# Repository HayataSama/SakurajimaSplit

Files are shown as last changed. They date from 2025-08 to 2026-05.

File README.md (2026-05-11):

# SakurajimaSplit

SakurajimaSplit is a 6x3 column stagger split mechanical keyboard. It's inspired by [Corne](https://github.com/foostan/crkbd), [Kyria](https://github.com/splitkb/kyria) and [Elephant42](https://github.com/illness072/elephant42).

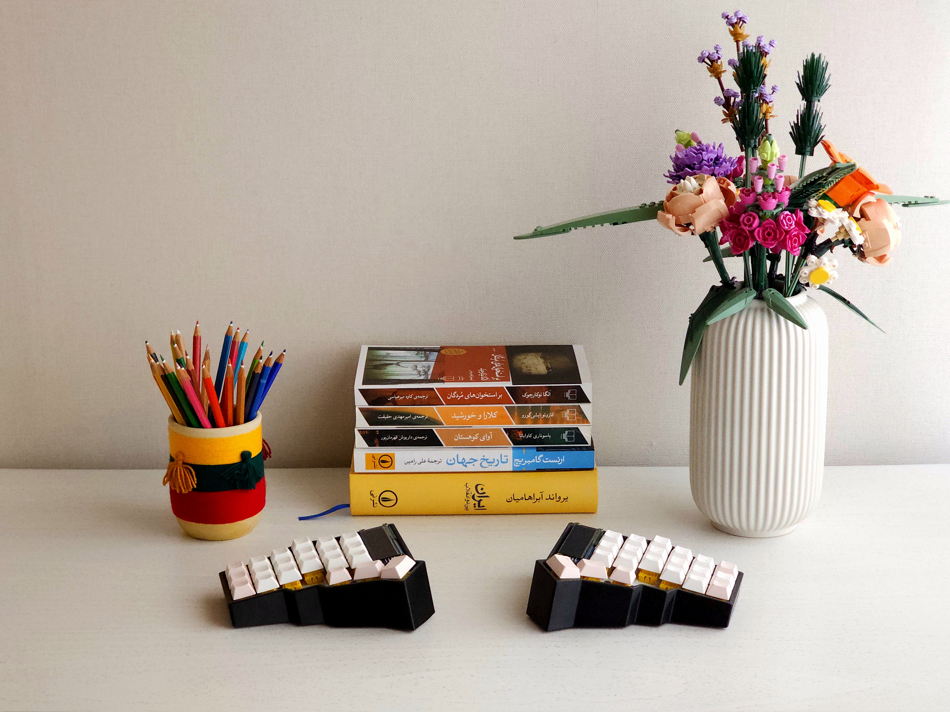
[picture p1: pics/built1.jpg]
SakurajimaSplit Fully Built


> [!NOTE]
> The master branch contains the most recent commits and is not meant for production. Gerbers and production files are available as a github release.
>
> This project was was made in KiCad 9.0 and FreeCAD 1.0. In addition to KiCad's default libraries, I used the [ebastler's marbastlib](https://github.com/ebastler/marbastlib) footprint and symbol library and [zykrah's kicad-kle-placer](https://github.com/zykrah/kicad-kle-placer) plugin. Using other versions may introduce bugs and/or inconsistencies therefore is discouraged.

## Features

- QMK compatible
- Cherry MX switch profile
- 3-Key thumb cluster
- 10-Degree sideways tilt
- SSD1305 OLED display
- W25Q Flash Storage for storing animations
- USB-C connector

## Motivation

I've been interested in mechanical keyboard for a few years now. I got my endgame keyboard (Mode Envoy) a while back and it's been my daily driver since. A while ago I suddenly became interested in split mechanical keyboards. Something about them being tiny and portable, also having this cyberpunky feeling made them appealing to me.

Apparently ortholinear keyboards are also more comfortable to type on. (Not sure how true this is but now that I've built this keyboard and am using it on daily basis, I should say it feels so damn nice to type with!)

I'm also an electrical engineering student and I have some experience designing PCBs. With all these in mind I thought, why not? Why not build a fully custom keyboard, tailored exactly to my needs? A few months later and here we are!

## Why Sakurajima?

Because Mai Sakurajima is the best girl.

## The Journey and Some Notes

This was my first experience designing a keyboard (and a handheld device in general). My approach for designing the layout was to put my fingers on a piece of paper (in the supposedly most comfortable position) and mark under each of my fingertips to find the best position for the home row. Then I measured the distance between keys and rounded them up to the closest standard value. (keyboard "u" units).

For the thumb cluster in addition to the fingertip, I also marked my thumb's joint (MCP joint?) on the paper to find the center of the circle where the thumb keys would be placed. Then I did some basic geometry to find the angle and distance of each key with respect to the center.

I don't know if this is the best approach or even a good approach, but it was fairly easy to do and the end result is great.

Let's talk about electronics. I know I've used a lot a questionable components in this keyboard, one's that are not generally common in keyboards or are not easily found. Believe me, I asked myself this question so many times too! Jokes aside, there were 3 main factors contributing to the component selection. First, this was a one off keyboard that I wanted to make for myself, so price didn't matter. Second, I wanted to try using different parts in my board from what I usually use, to gain more experience about electronics and get a feel for different components. And third (and probably the most important), I live in a heavily sanctioned country, so I don't have easy access to many electronic components because distributors like DigiKey or Mouser don't operate here. I had to work with what was available on the market.

This lead to some weird and frustrating design decisions that I regret.

The first mistake was choosing an SSD1305-based OLED display. I chose this specific display because it's panel was much larger than most common OLED displays on the market and I thought it would look good on the keyboard. The OLED driver is very similar to SSD1306 but is not officially supported by QMK. This is not a big problem by itself as QMK is an open-source firmware and you're free to modify the source code to add support for your display. The main problem is that this OLED module is 128x33 pixels and not 128x32 pixels like most OLED modules are! This creates many memory related issues and incompatibility with QMK which I have yet to solve!

The next not so great decision was choosing a WSON package for hand soldering! The voltage regulator IC is very very tiny and without proper tools like a microscope and a hotplate (which I don't have) is very difficult to hand solder. I don't know what I was thinking when picking parts, but now I've learned (the hard way!) to pay more attention to package sizes.

A big missed opportunity was not making this keyboard wireless. I could probably use an STM32 W-series MCU to make this keyboard Bluetooth-enabled. At the time, I chose to not go this route mainly because I wanted to keep things simple and build something that actually just works. I might create a new revision of this keyboard, fix the stated issues (and some others) and add new features like wireless connectivity in the future.

## Limitations

QMK doesn't currently support W25Q flash storages. I plan on writing a driver for these ICs and add it to QMK in the future, but for now this chip is basically useless.

## Gallery

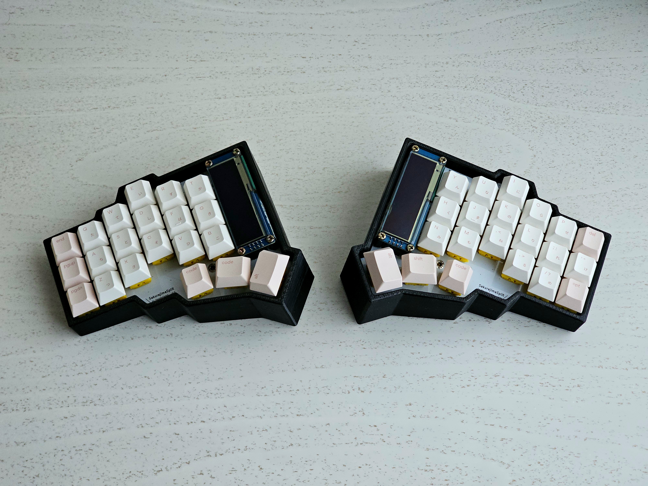
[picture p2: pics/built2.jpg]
SakurajimaSplit Fully Built Top View

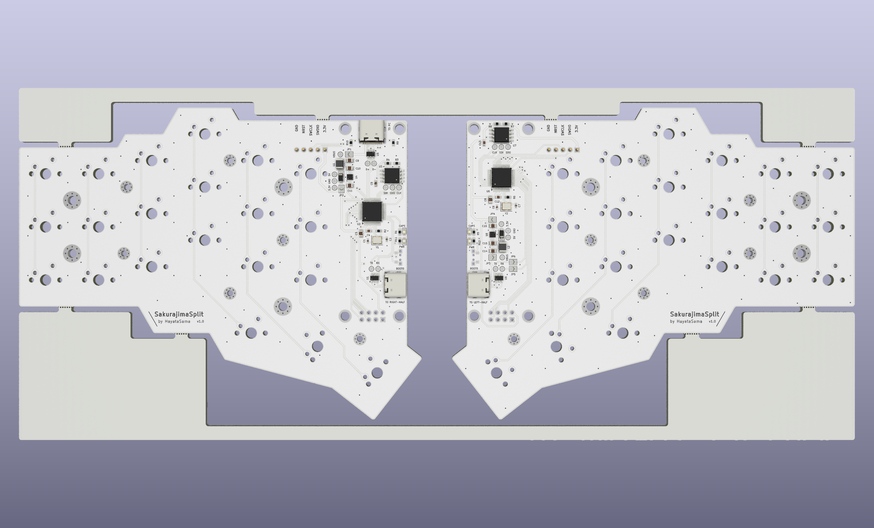
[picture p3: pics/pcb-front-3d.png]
PCB 3D Front View

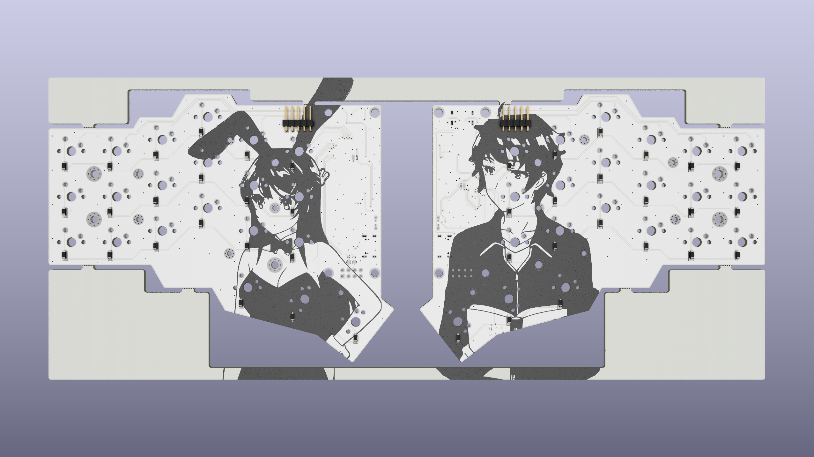
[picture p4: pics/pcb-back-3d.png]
PCB 3D Back View

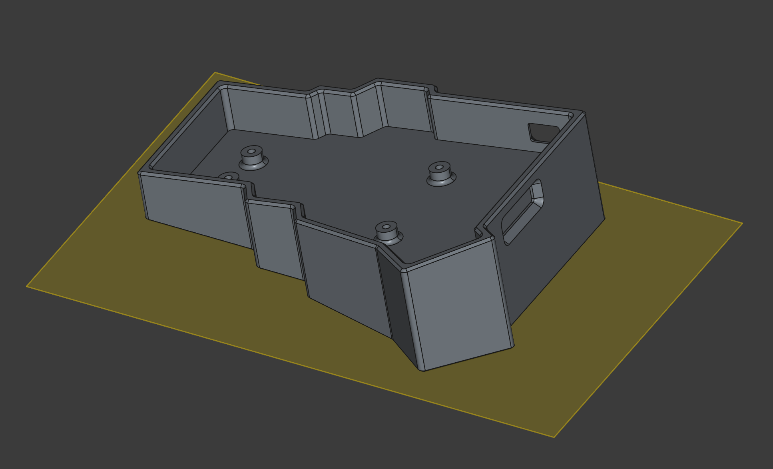
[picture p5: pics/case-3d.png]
3D Model of The Case


## Acknowledgements

I have to say a big thank you to [Joe Scotto](https://youtube.com/@joe_scotto) for his YouTube channel which was big source of motivation and guidance in this project and [ebastler](https://github.com/ebastler) for his great KiCad library which made my life a lot easier! Also a big thank you to all the people active in the mechanical keyboard community, open-source contributors and the QMK team!

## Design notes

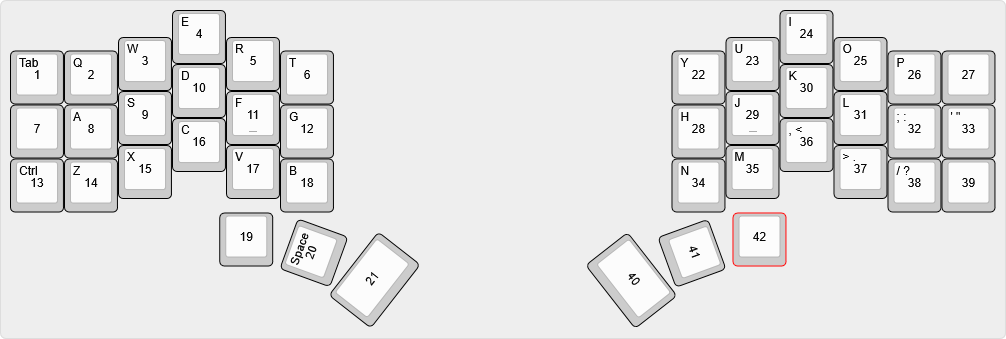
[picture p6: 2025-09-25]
docs/SakurajimaSplit_KLE.png

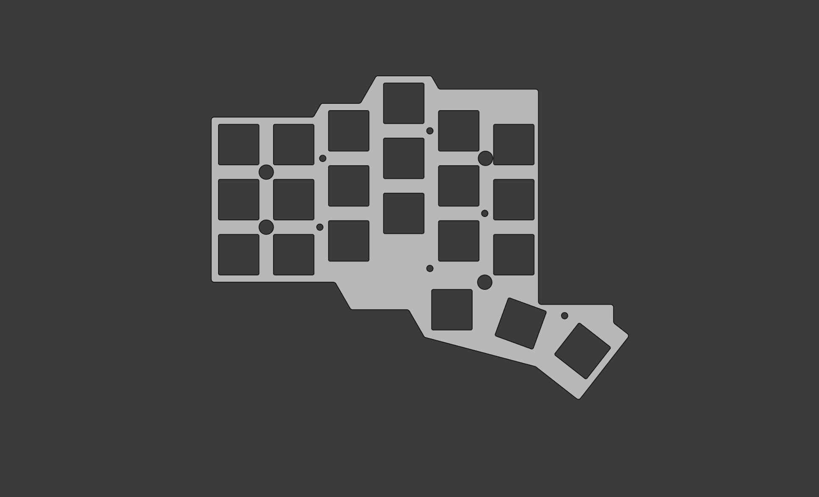
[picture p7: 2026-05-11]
pics/plate-3d.png

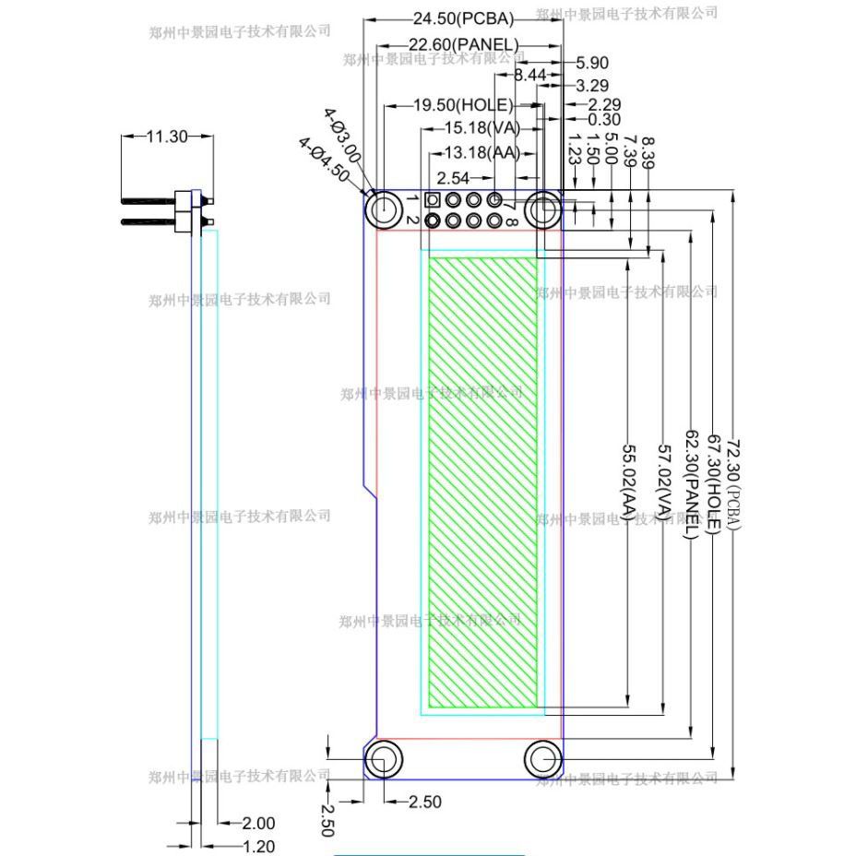
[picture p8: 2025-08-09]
docs/lcd_dimensions.jpg

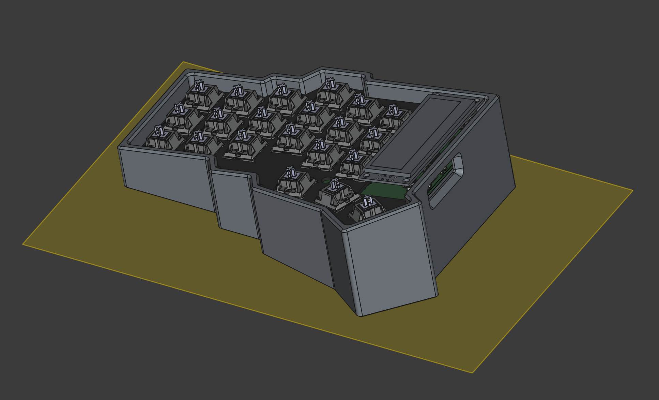
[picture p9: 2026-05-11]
pics/keyboard-3d.png

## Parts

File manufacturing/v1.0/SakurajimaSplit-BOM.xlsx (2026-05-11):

SakurajimaSplit Bill of Materials
Reference | Manufacturer | Part Number | QTY | Description | Link
PCB
C1,C2,C6,C7 | Murata | GRM1555C1H220JA01D | 4 | Ceramic Capacitor | https://lionelectronic.ir/products/5170-GRM1555C1H220JA01D
C3,C8,C10,C11,C15,C16 | Murata | GRM21BR61H475KE51L | 6 | Ceramic Capacitor | https://lionelectronic.ir/products/4714-GRM21BR61H475KE51L
C4,C5,C12,C13 | Murata | GRM188R72A104KA35D | 4 | Ceramic Capacitor | https://lionelectronic.ir/products/4734-GRM188R72A104KA35D
C9,C14 | Murata | GRM21BR61H475KE51L | 2 | Ceramic Capacitor | https://lionelectronic.ir/products/4714-GRM21BR61H475KE51L
D1,D2,D3,D4,D5,D6,D7,D8,D9,D10,D11,D12,D13,D14,D15,D16,D17,D18,D19,D20,D21,D22,D23,D24,D25,D26,D27,D28,D29,D30,D31,D32,D33,D34,D35,D36,D37,D38,D39,D40,D41,D42 | Jingdao Microelectronics | 1N4148W | 42 | Diode | https://lionelectronic.ir/products/2289-1N4148W
D43,D46 | XINGLIGHT | XL-1608UWC-04 | 2 | White LED | https://lionelectronic.ir/products/2215-XL-1608UWC-04
D44,D47 | Diodes Incorporated | B0530W-7-F | 2 | Schottky Diode | https://lionelectronic.ir/products/5692-B0530W-7-F
D45,D48 | XINGLIGHT | XL-1608UGC-04 | 2 | Green LED | https://lionelectronic.ir/products/2212-XL-1608UGC-04
J1,J4 |  |  | 2 | 2.54mm Right-Angle Male Pin Header
J2,J5,J7 | G-Switch | GT-USB-7010ASV | 3 | USB Type-C Receptacle | https://lionelectronic.ir/products/3242-GT-USB-7010ASV
L1,L2 | Murata | DFE322512F-100M | 2 | Inductor | https://lionelectronic.ir/products/4794-DFE322512F-100M%3DP2
R1,R5,R11,R12 | VO Sub Brand (ER) | SER0603F330R | 4 | Resistor | https://lionelectronic.ir/products/1182-SER0603F330R
R2,R6 |  |  | 2 | Resistor
R3,R4,R7,R8,R9,R10 | UniOhm | 0603WAF5101T5E | 6 | Resistor | https://lionelectronic.ir/products/1212-0603WAF5101T5E
SW1,SW2 | XKB Connection | TS-1010B-B-A | 2 | Tactile Switch | https://lionelectronic.ir/products/5480-TS-1010B-B-A
U1,U5,U9 | STMicroelectronics | USBLC6-4SC6 | 3 | ESD Protection | https://lionelectronic.ir/products/4780-USBLC6-4SC6
U2,U6 | STMicroelectronics | STM32G0B1CBT6 | 2 | MCU | https://lionelectronic.ir/products/2851-STM32G0B1CBT6
U3,U7 | Winbond | W25Q128JVSIQ | 2 | NOR Flash | https://lionelectronic.ir/products/532-W25Q128JVSIQ
U4,U8 | Texas Instruments | TLV76733DRVR | 2 | LDO | https://lionelectronic.ir/products/4877-TLV76733DRVR
U10,U11 |  |  | 2 | OLED Display | https://thecaferobot.com/store/2-23-inch-spi-iic-oled-display-module-with-ssd1305-driver
U10,U11 | Gosun | PBD-2.54-2X4GF | 2 | 4x2 2.54mm Female Pin Header | https://lionelectronic.ir/products/5841-PBD-2.54-2X4GF
Y1,Y2 | YXC | X32258MSB4SI | 2 | 8MHz Crystal | https://lionelectronic.ir/products/4281-X32258MSB4SI
Mechanical
 |  |  | 8 | M3 Screw | https://lionelectronic.ir/products/5042-M3x6-Screw
 |  |  | 8 | M3 Nut | https://lionelectronic.ir/products/5043-M3-Hex-Nut
 |  |  | 8 | M3 Spacer | https://lionelectronic.ir/products/4998-M3-10
 |  |  | 8 | M2 Screw | https://www.sanatbazar.com/product/565-%D9%BE%DB%8C%DA%86-%DA%86%D9%87%D8%A7%D8%B1%D8%B3%D9%88-%D8%B3%D8%B1%DA%AF%D8%B1%D8%AF-%D8%A7%D8%B3%D8%AA%D9%88%D8%A7%D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
 |  |  | 8 | M2 Heat Insert | https://thecaferobot.com/store/m2-threaded-insert-nut-3mm-outer-diamete
 |  |  | 8 | Rubber Feet | https://www.digikala.com/product/dkp-20962426

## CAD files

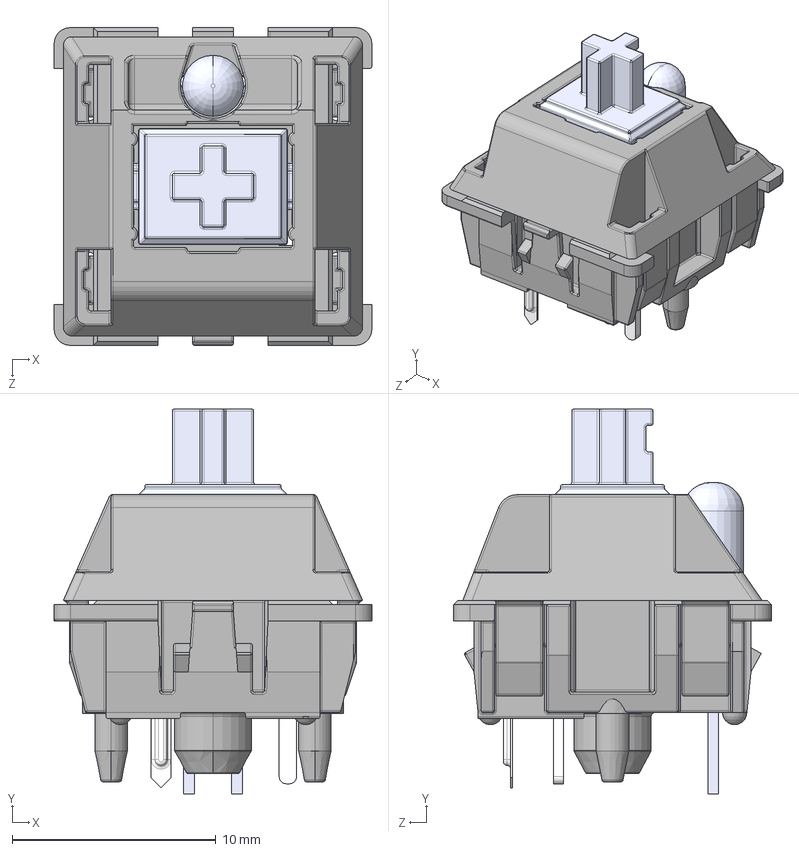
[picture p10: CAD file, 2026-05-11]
CAD/STEP/MX.STEP
15.6 x 18.9 x 15.6 mm
MX 轴 按键′_ü___¨1
MX 轴 轴体áì_¨￠¨__
MX粣 拸簽LEDLEDLED
MX轴 轴体 底部 μ×2__默认_á2____è_
针脚___默认__è_

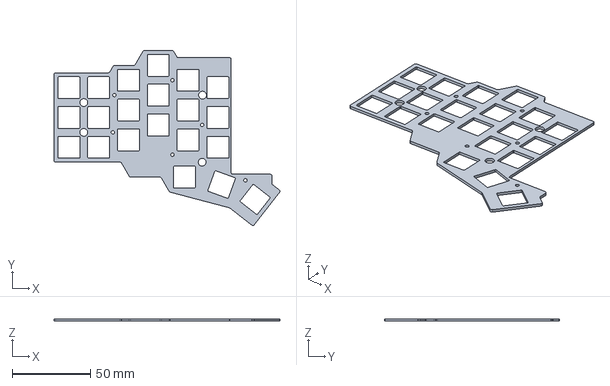
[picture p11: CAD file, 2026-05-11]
manufacturing/v1.0/Mechanical/SakurajimaSplit-Plate.step
144.5 x 112.0 x 1.50 mm

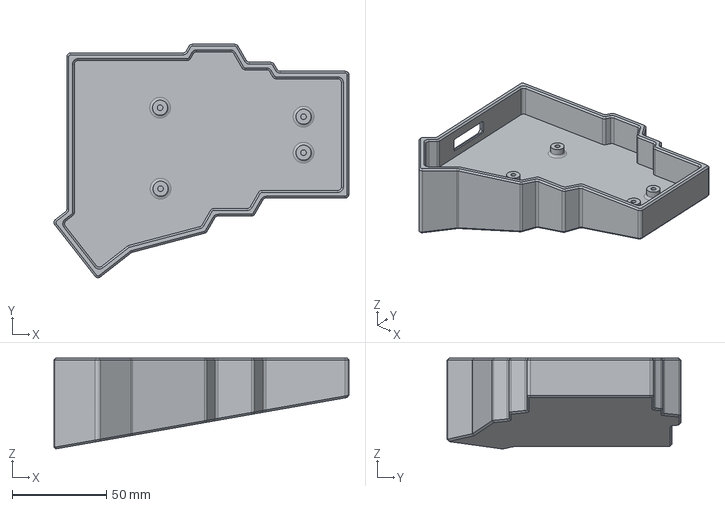
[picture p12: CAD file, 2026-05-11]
manufacturing/v1.0/Mechanical/SakurajimaSplit-Right Case.step
156.1 x 123.6 x 48.1 mm

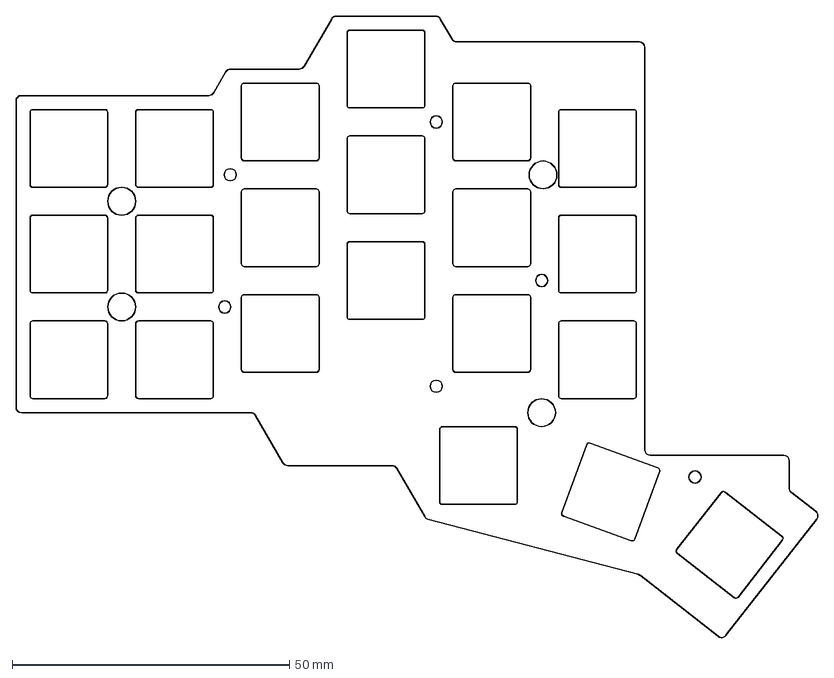
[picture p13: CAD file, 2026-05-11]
manufacturing/v1.0/Mechanical/SakurajimaSplit-Plate-2D.dxf
144.5 x 112.0 mm

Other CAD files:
manufacturing/v1.0/Mechanical/SakurajimaSplit-Left Case.step
manufacturing/v1.0/Mechanical/SakurajimaSplit-Left Case.stl
manufacturing/v1.0/Mechanical/SakurajimaSplit-Plate.stl
manufacturing/v1.0/Mechanical/SakurajimaSplit-Right Case.stl

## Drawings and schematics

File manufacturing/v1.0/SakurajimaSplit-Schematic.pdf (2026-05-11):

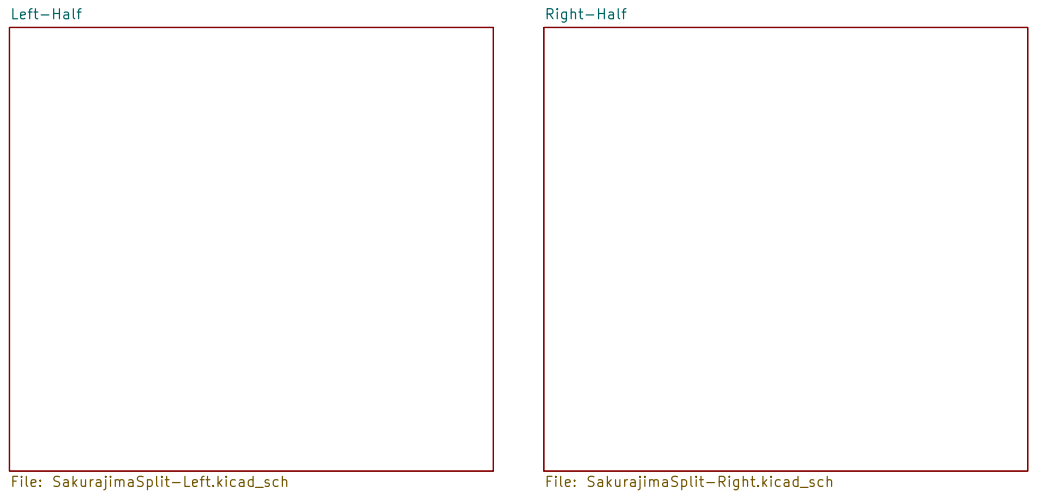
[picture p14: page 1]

Left-Half File: SakurajimaSplit-Left.kicad_sch

Right-Half File: SakurajimaSplit-Right.kicad_sch

https://github.com/HayataSama/SakurajimaSplit
HayataSama
Sheet: /
File: SakurajimaSplit.kicad_sch
Title: SakurajimaSplit

Size: A3 | Rev: 1.0 | F Date: 2025-05-21
KiCad E.D.A. 10.0.1 | Id: 1/7

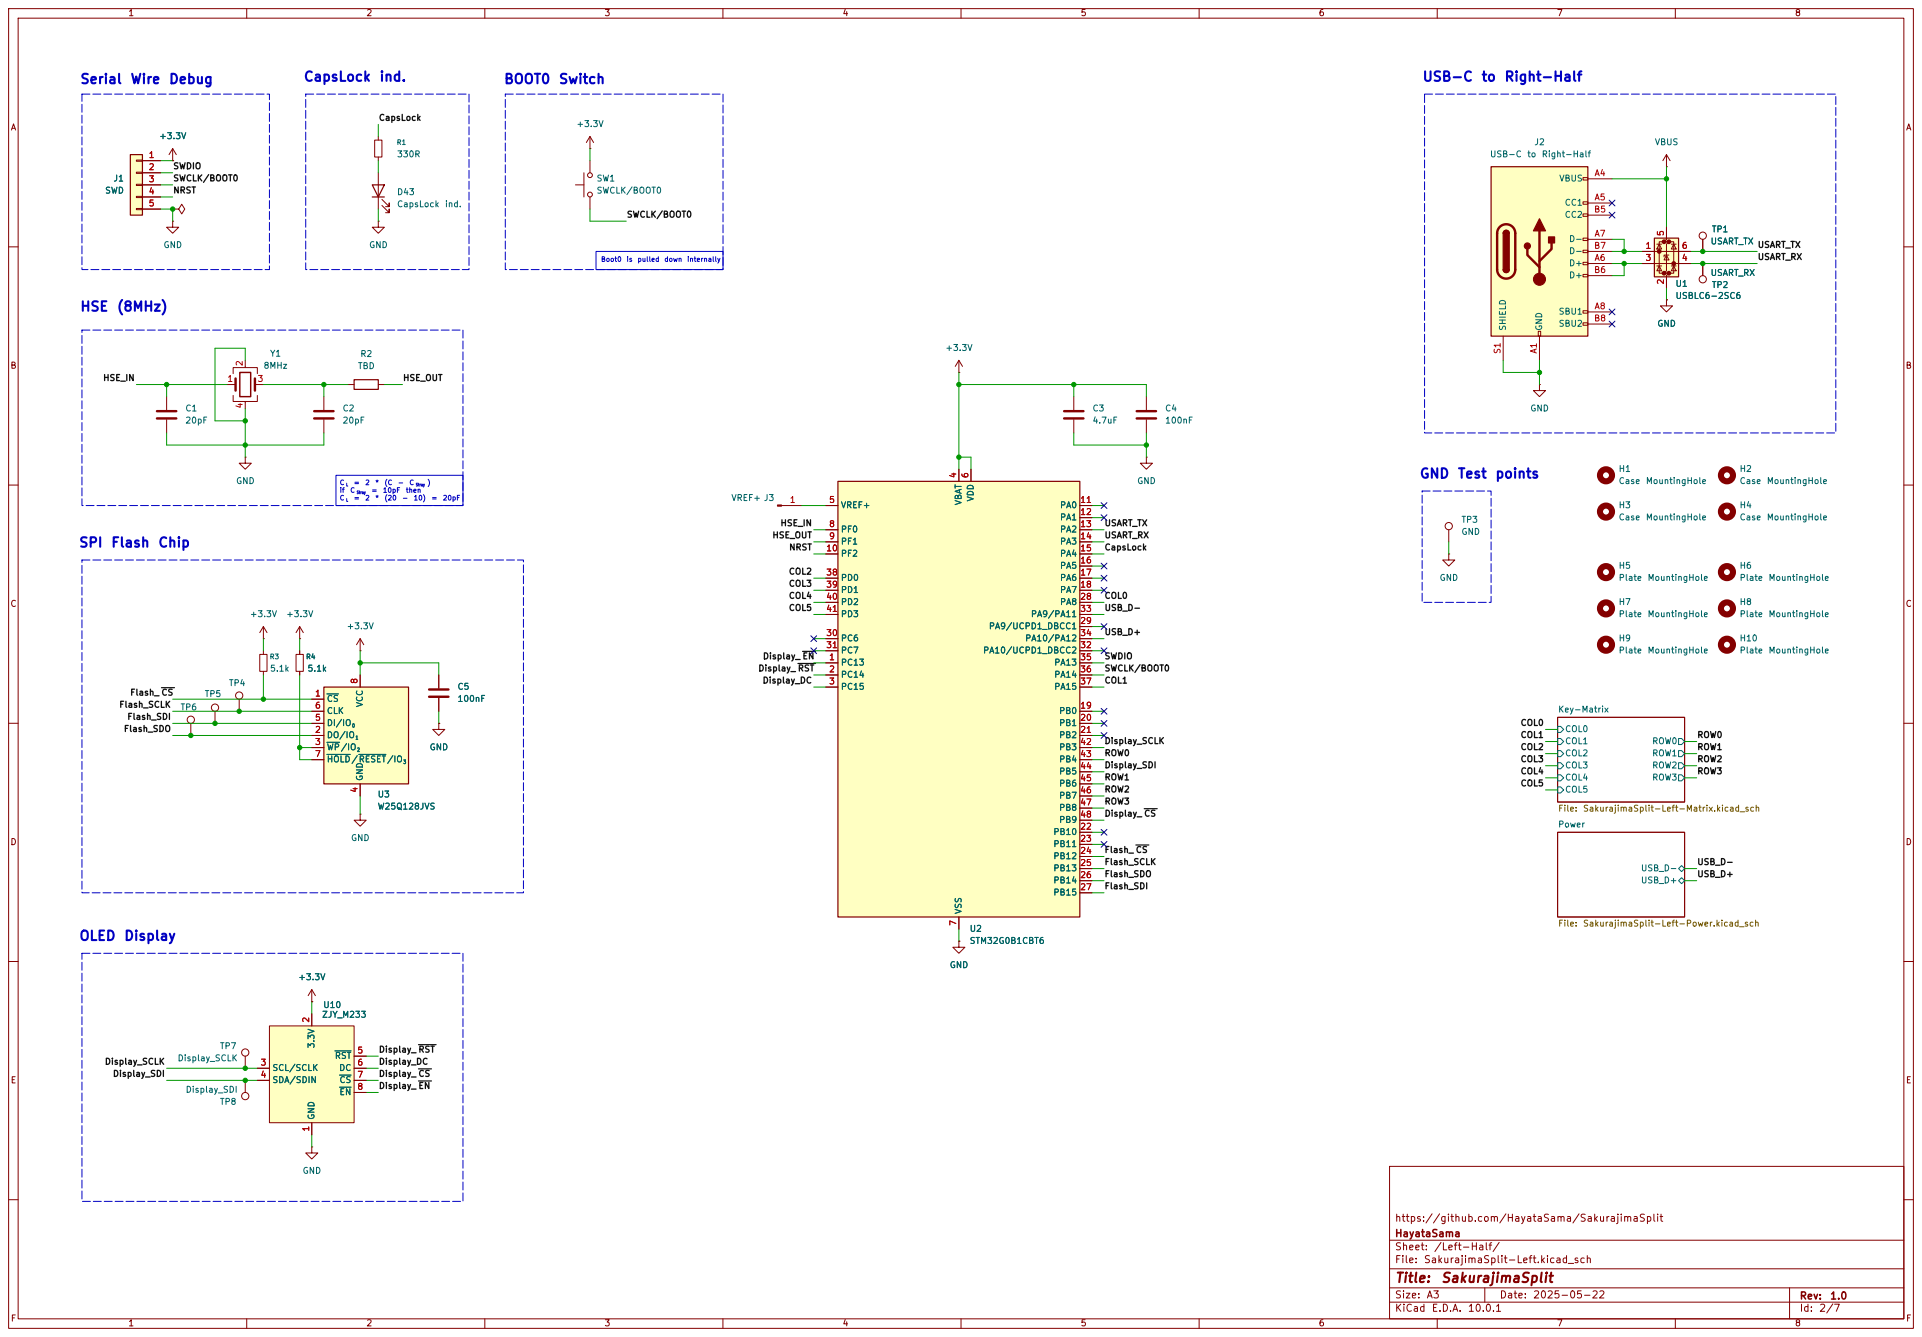
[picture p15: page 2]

if C Stray = 10pF then C L = 2 * (20 - 10) = 20pF Serial Wire Debug

USB-C to Right-Half

J2 USB-C to Right-Half R1330R

6U1USBLC6-2SC6 H3Case MountingHole H5Plate MountingHole H7Plate MountingHole H9Plate MountingHole GND

4 DI/IO0 5 CLK 6 HOLD/RESET/IO3 7 VCC

Power File: SakurajimaSplit-Left-Power.kicad_sch ROW0 ROW1 ROW2 ROW3 COL0 COL1 COL2 COL3 COL4 COL5 Key-Matrix File: SakurajimaSplit-Left-Matrix.kicad_sch

https://github.com/HayataSama/SakurajimaSplit USB_D+

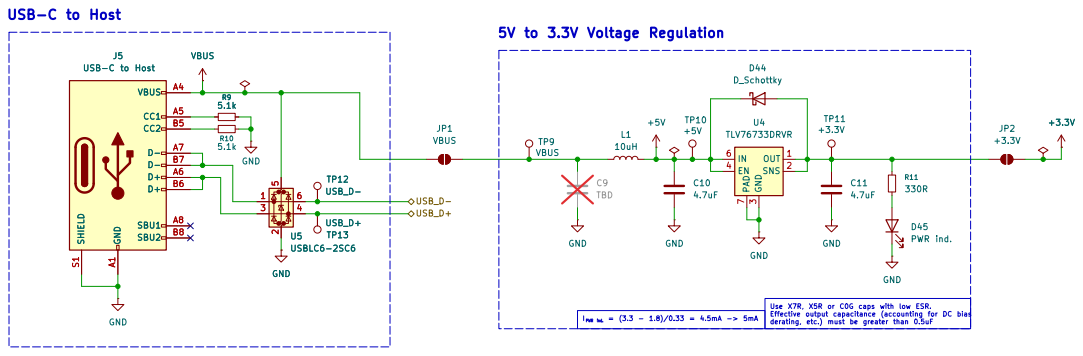
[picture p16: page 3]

J5 USB-C to Host GND A1

https://github.com/HayataSama/SakurajimaSplit
HayataSama
Sheet: /Left-Half/Power/
File: SakurajimaSplit-Left-Power.kicad_sch

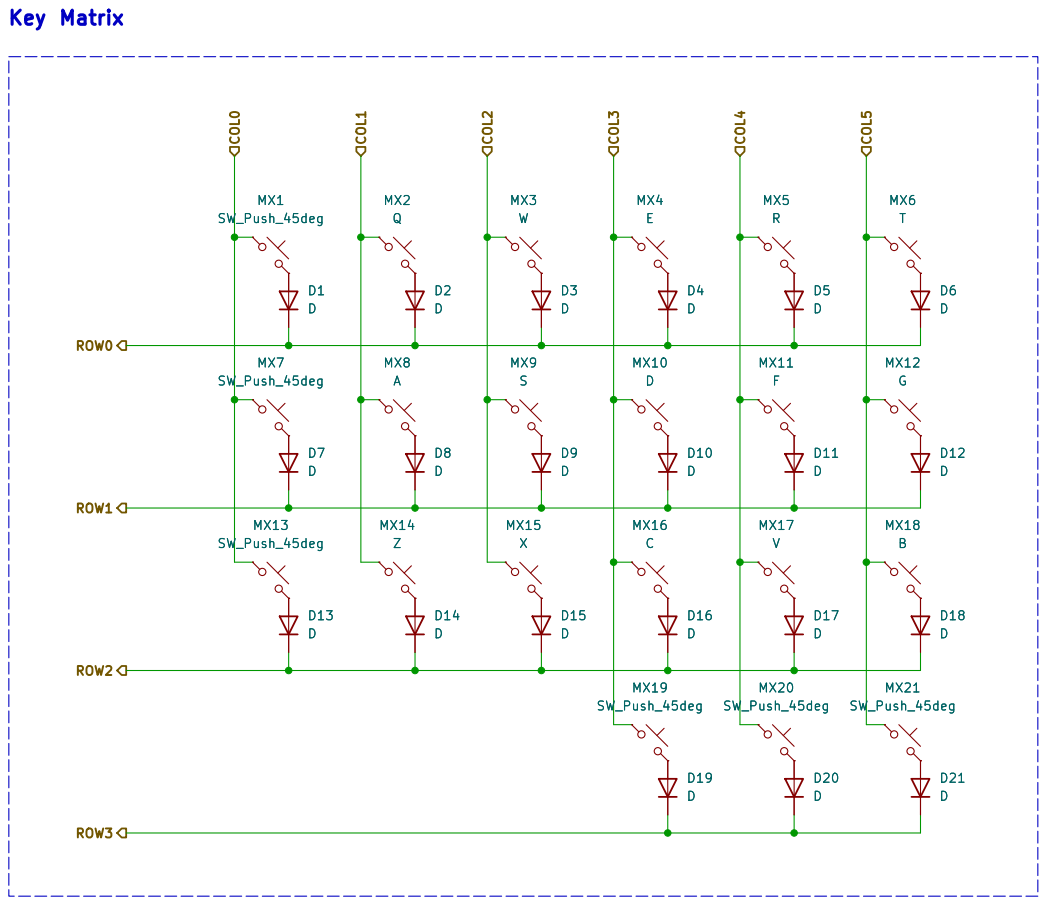
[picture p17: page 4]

https://github.com/HayataSama/SakurajimaSplit
HayataSama
Sheet: /Left-Half/Key-Matrix/
File: SakurajimaSplit-Left-Matrix.kicad_sch

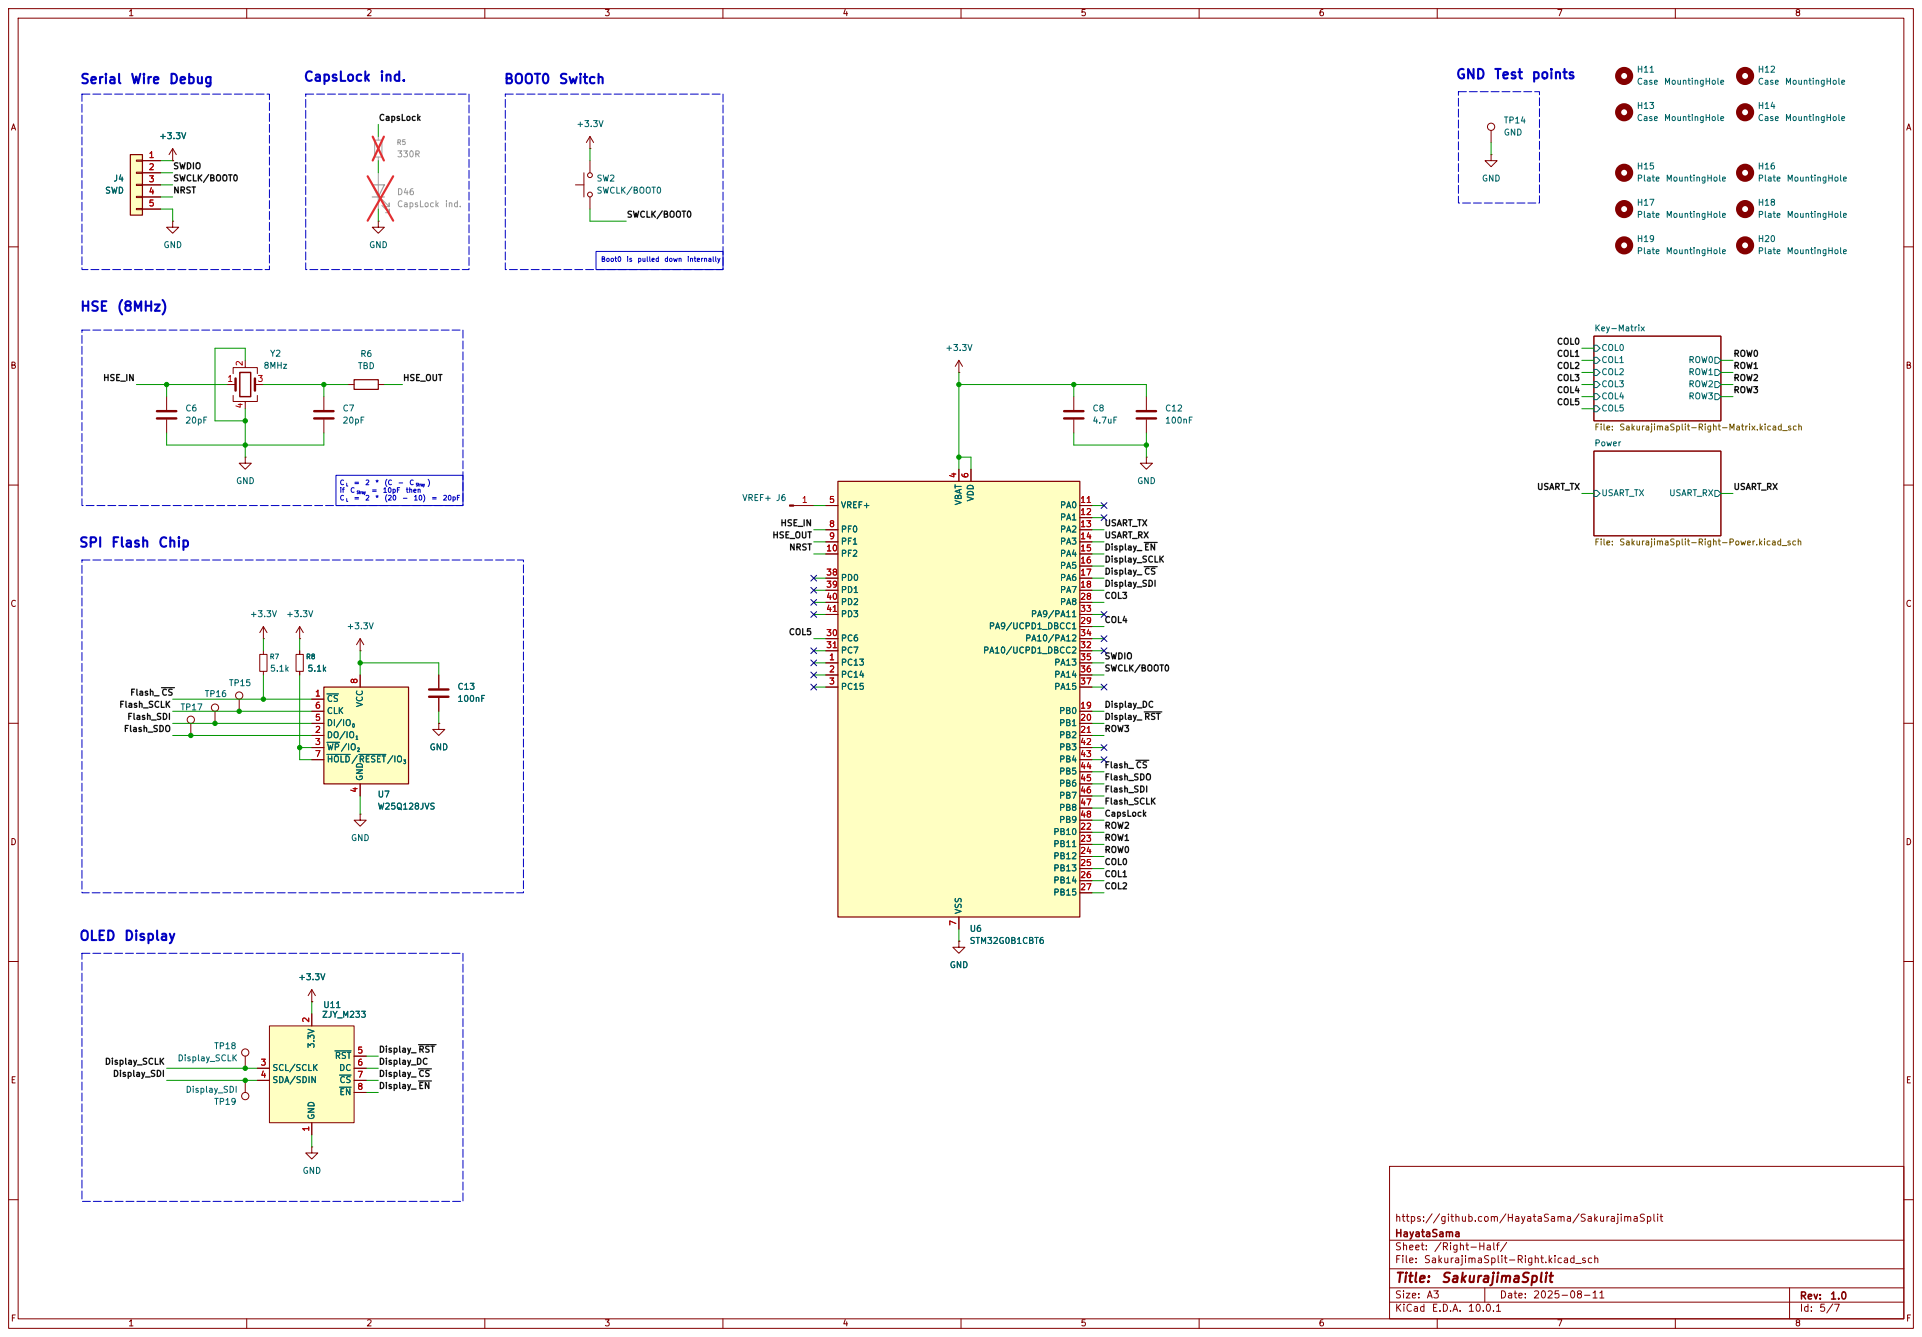
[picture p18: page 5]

4 DI/IO0 5 CLK 6 HOLD/RESET/IO3 7 VCC

https://github.com/HayataSama/SakurajimaSplit
HayataSama
Sheet: /Right-Half/
File: SakurajimaSplit-Right.kicad_sch

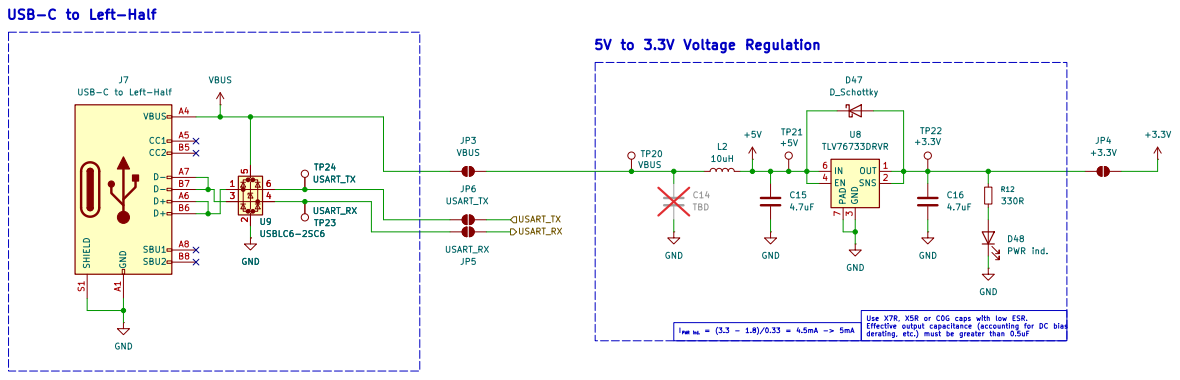
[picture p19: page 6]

https://github.com/HayataSama/SakurajimaSplit
HayataSama
Sheet: /Right-Half/Power/
File: SakurajimaSplit-Right-Power.kicad_sch

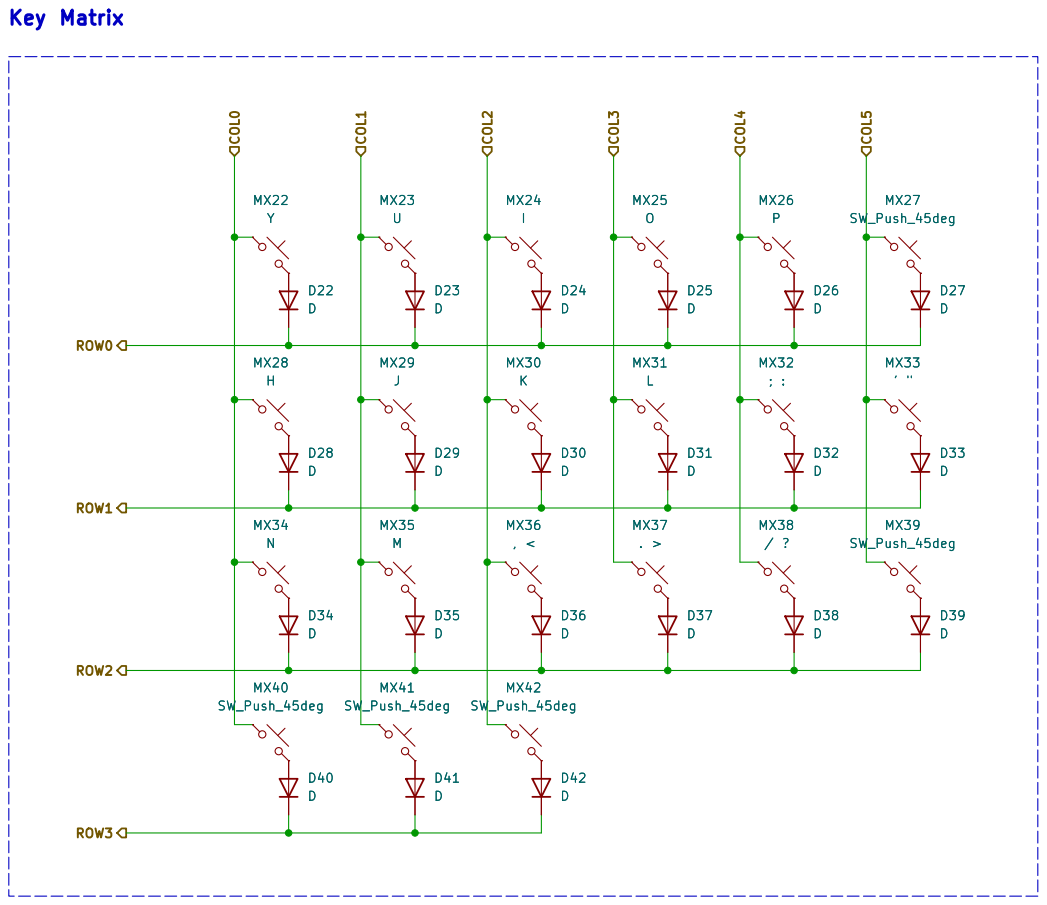
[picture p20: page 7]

https://github.com/HayataSama/SakurajimaSplit
HayataSama
Sheet: /Right-Half/Key-Matrix/
File: SakurajimaSplit-Right-Matrix.kicad_sch

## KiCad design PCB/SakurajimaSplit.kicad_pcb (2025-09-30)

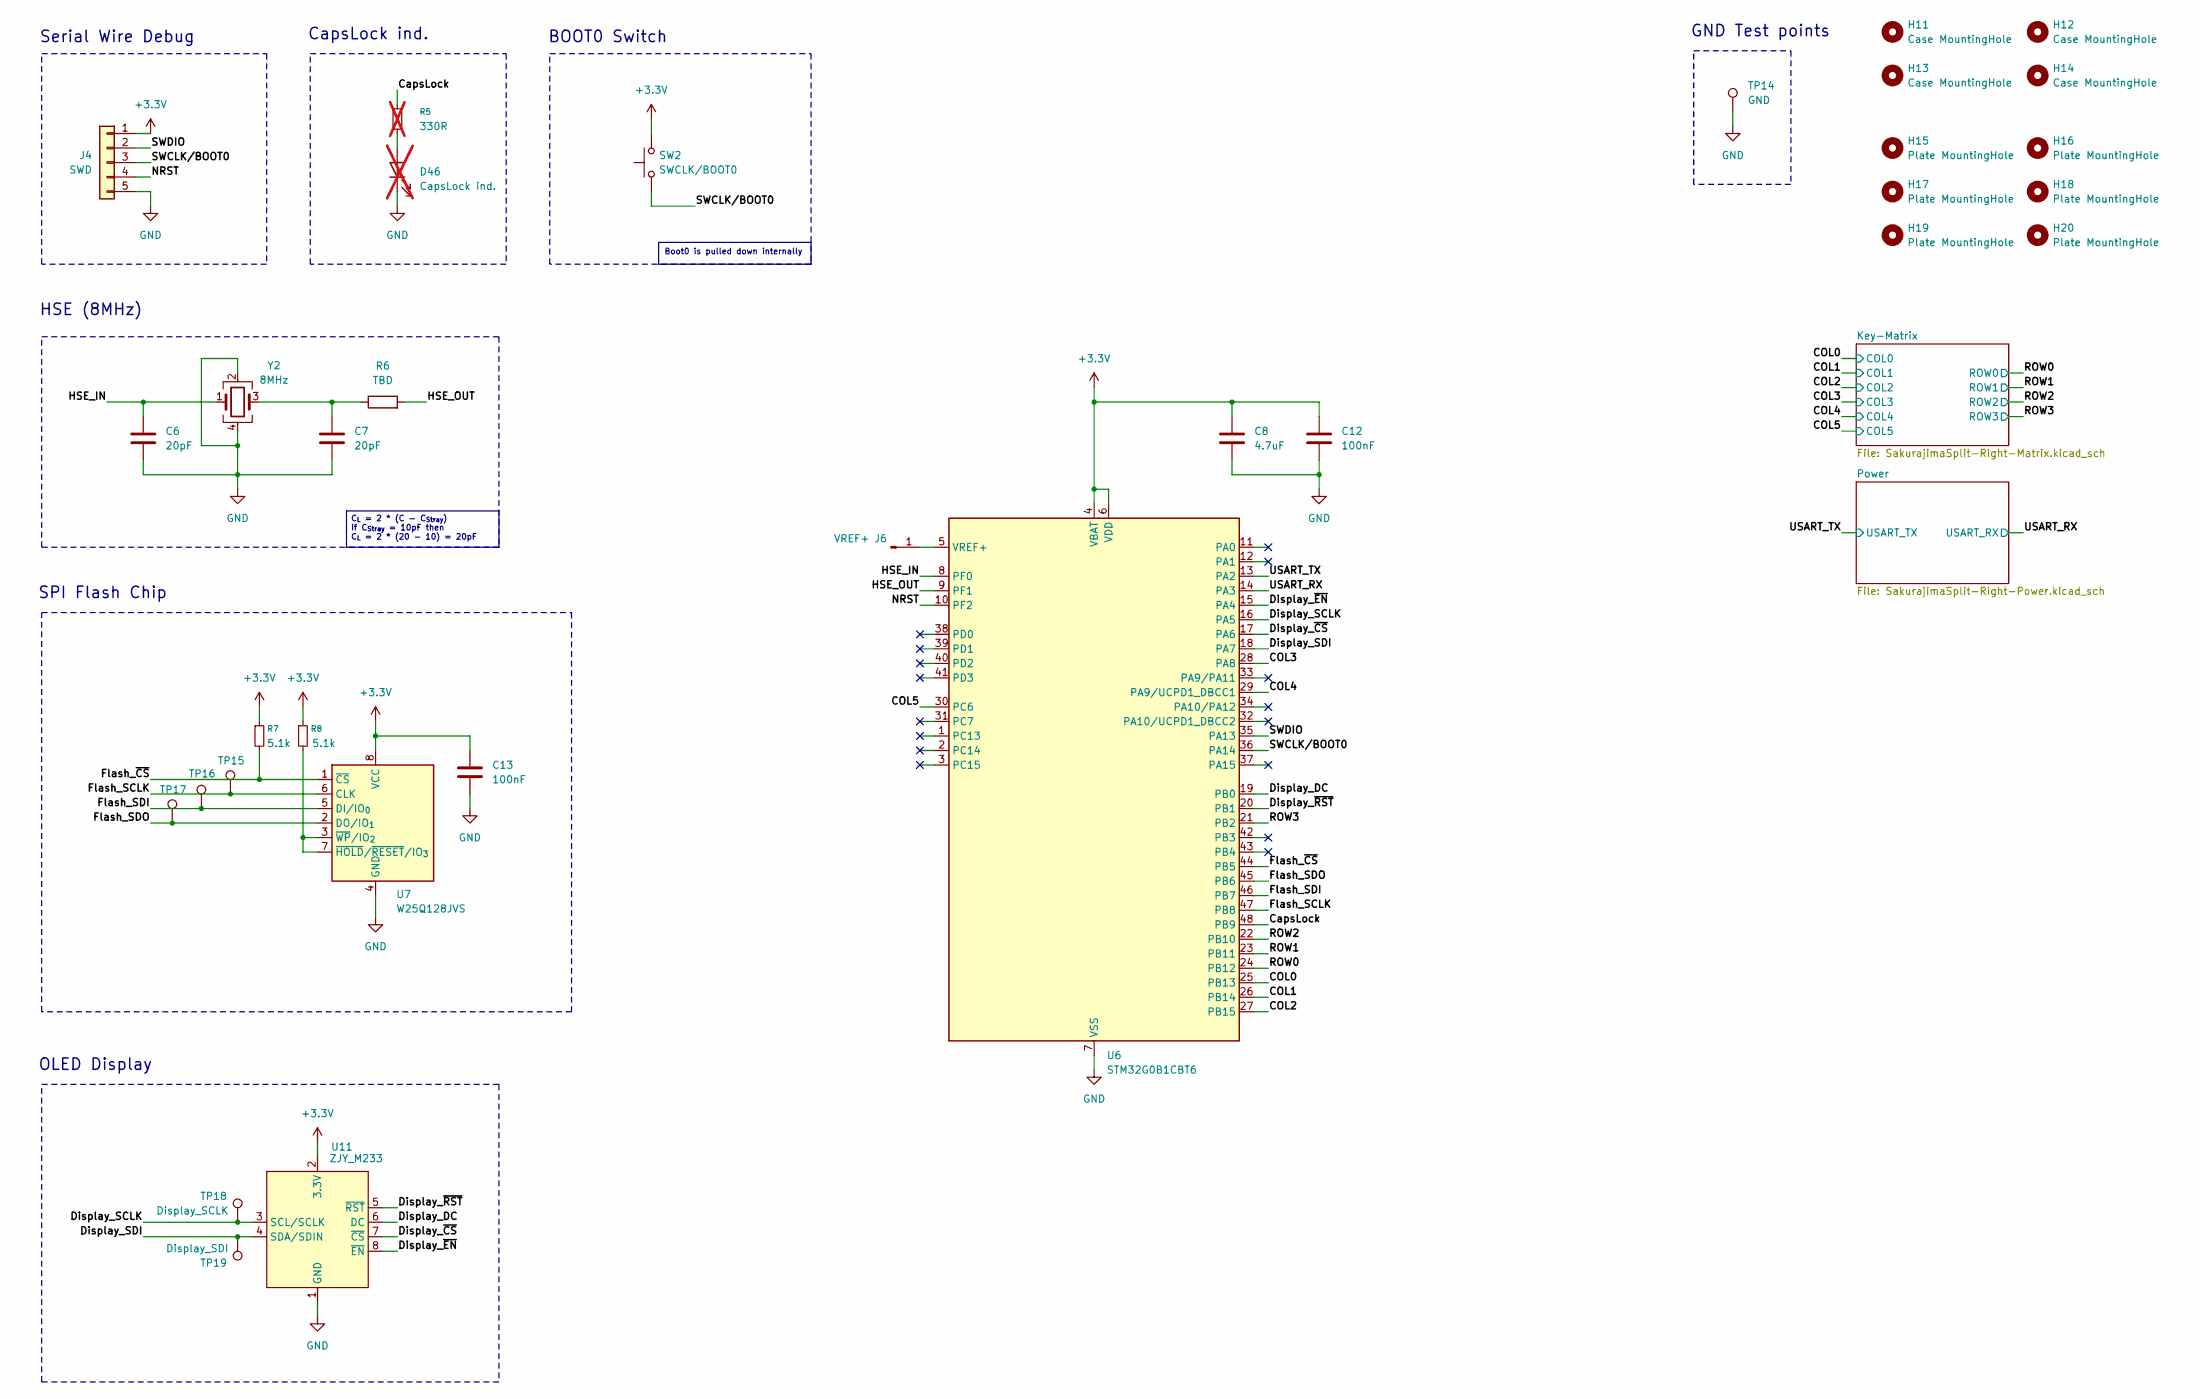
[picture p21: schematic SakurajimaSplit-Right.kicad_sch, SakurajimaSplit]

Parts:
C6, C7: 20pF; C_0402_1005Metric_Pad0.74x0.62mm_HandSolder; Manufacturer Part No. GRM1555C1H220JA01D
C8: 4.7uF; C_0805_2012Metric; Manufacturer Part No. GRM21BR61H475KE51L
C12, C13: 100nF; C_0603_1608Metric; Manufacturer Part No. GRM188R72A104KA35D
D46: CapsLock ind.; LED_0603_1608Metric; Manufacturer Part No. XL-1608UWC-04; not fitted
H11, H12, H13, H14: Case MountingHole; MountingHole_3.2mm_M3_Pad_Via
H15, H16, H17, H18, H19, H20: Plate MountingHole; MountingHole_2.2mm_M2_Pad_Via
J4: SWD; PinHeader_1x05_P2.54mm_Horizontal
J6: VREF+; SolderWirePad_1x01_SMD_1x2mm
R5: 330R; R_0603_1608Metric; Manufacturer Part No. SER0603F330R; not fitted
R6: TBD; R_0603_1608Metric
R7, R8: 5.1k; R_0603_1608Metric; Manufacturer Part No. 0603WAF5101T5E
SW2: SWCLK/BOOT0; SW_Push_TS-1010B; Manufacturer Part No. TS-1010B-B-A
TP14: GND; TestPoint_Pad_Circular_1.3mm
TP15: Flash_SCLK; TestPoint_Pad_Circular_1.3mm
TP16: Flash_SDI; TestPoint_Pad_Circular_1.3mm
TP17: Flash_SDO; TestPoint_Pad_Circular_1.3mm
TP18: Display_SCLK; TestPoint_Pad_Circular_1.3mm
TP19: Display_SDI; TestPoint_Pad_Circular_1.3mm
U6: STM32G0B1CBT6; LQFP-48_7x7mm_P0.5mm; Manufacturer Part No. STM32G0B1CBT6
U7: W25Q128JVS; SOIC-8_5.3x5.3mm_P1.27mm; Manufacturer Part No. W25Q128JVSIQ
U11: ZJY_M233; OLED_SSD1305
Y2: 8MHz; Crystal_SMD_3225-4Pin_3.2x2.5mm; Manufacturer Part No. X32258MSB4SI

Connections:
+3.3V: C8.1, C12.1, C13.1, J4.1, R7.1, R8.1, SW2.2, U6.4 (VBAT), U6.6 (VDD), U7.8 (VCC), U11.2 (3.3V); also elsewhere on the board
/Right-Half/COL0: U6.25 (PB13); also elsewhere on the board
/Right-Half/COL1: U6.26 (PB14); also elsewhere on the board
/Right-Half/COL2: U6.27 (PB15); also elsewhere on the board
/Right-Half/COL3: U6.28 (PA8); also elsewhere on the board
/Right-Half/COL4: U6.29 (PA9/UCPD1_DBCC1); also elsewhere on the board
/Right-Half/COL5: U6.30 (PC6); also elsewhere on the board
/Right-Half/CapsLock: R5.1, U6.48 (PB9)
/Right-Half/Display_DC: U6.19 (PB0), U11.6 (DC)
/Right-Half/Display_SCLK: TP18.1, U6.16 (PA5), U11.3 (SCL/SCLK)
/Right-Half/Display_SDI: TP19.1, U6.18 (PA7), U11.4 (SDA/SDIN)
/Right-Half/Display_~CS: U6.17 (PA6), U11.7 (~CS)
/Right-Half/Display_~EN: U6.15 (PA4), U11.8 (~EN)
/Right-Half/Display_~RST: U6.20 (PB1), U11.5 (~RST)
/Right-Half/Flash_SCLK: TP15.1, U6.47 (PB8), U7.6 (CLK)
/Right-Half/Flash_SDI: TP16.1, U6.46 (PB7), U7.5 (DI/IO_{0})
/Right-Half/Flash_SDO: TP17.1, U6.45 (PB6), U7.2 (DO/IO_{1})
/Right-Half/Flash_~CS: R7.2, U6.44 (PB5), U7.1 (~CS)
/Right-Half/HSE_IN: C6.1, U6.8 (PF0), Y2.1
/Right-Half/HSE_OUT: R6.2, U6.9 (PF1)
/Right-Half/NRST: J4.4, U6.10 (PF2)
/Right-Half/ROW0: U6.24 (PB12); also elsewhere on the board
/Right-Half/ROW1: U6.23 (PB11); also elsewhere on the board
/Right-Half/ROW2: U6.22 (PB10); also elsewhere on the board
/Right-Half/ROW3: U6.21 (PB2); also elsewhere on the board
/Right-Half/SWCLK/BOOT0: J4.3, SW2.1, U6.36 (PA14)
/Right-Half/SWDIO: J4.2, U6.35 (PA13)
/Right-Half/USART_RX: U6.14 (PA3); also elsewhere on the board
/Right-Half/USART_TX: U6.13 (PA2); also elsewhere on the board
GND: C6.2, C7.2, C8.2, C12.2, C13.2, D46.1 (K), J4.5, TP14.1, U6.7 (VSS), U7.4 (GND), U11.1 (GND), Y2.2, Y2.4; also elsewhere on the board
unnamed: C7.1, R6.1, Y2.3
unnamed: D46.2 (A), R5.2
unnamed: J6.1, U6.5 (VREF+)
unnamed: R8.2, U7.3 (~WP/IO_{2}), U7.7 (~HOLD/~RESET/IO_{3})

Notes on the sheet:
HSE (8MHz)
SPI Flash Chip
Serial Wire Debug
BOOT0 Switch
OLED Display
GND Test points
CapsLock ind.
Boot0 is pulled down internally
C_{L} = 2 * (C - C_{Stray}) if C_{Stray} = 10pF then C_{L} = 2 * (20 - 10) = 20pF

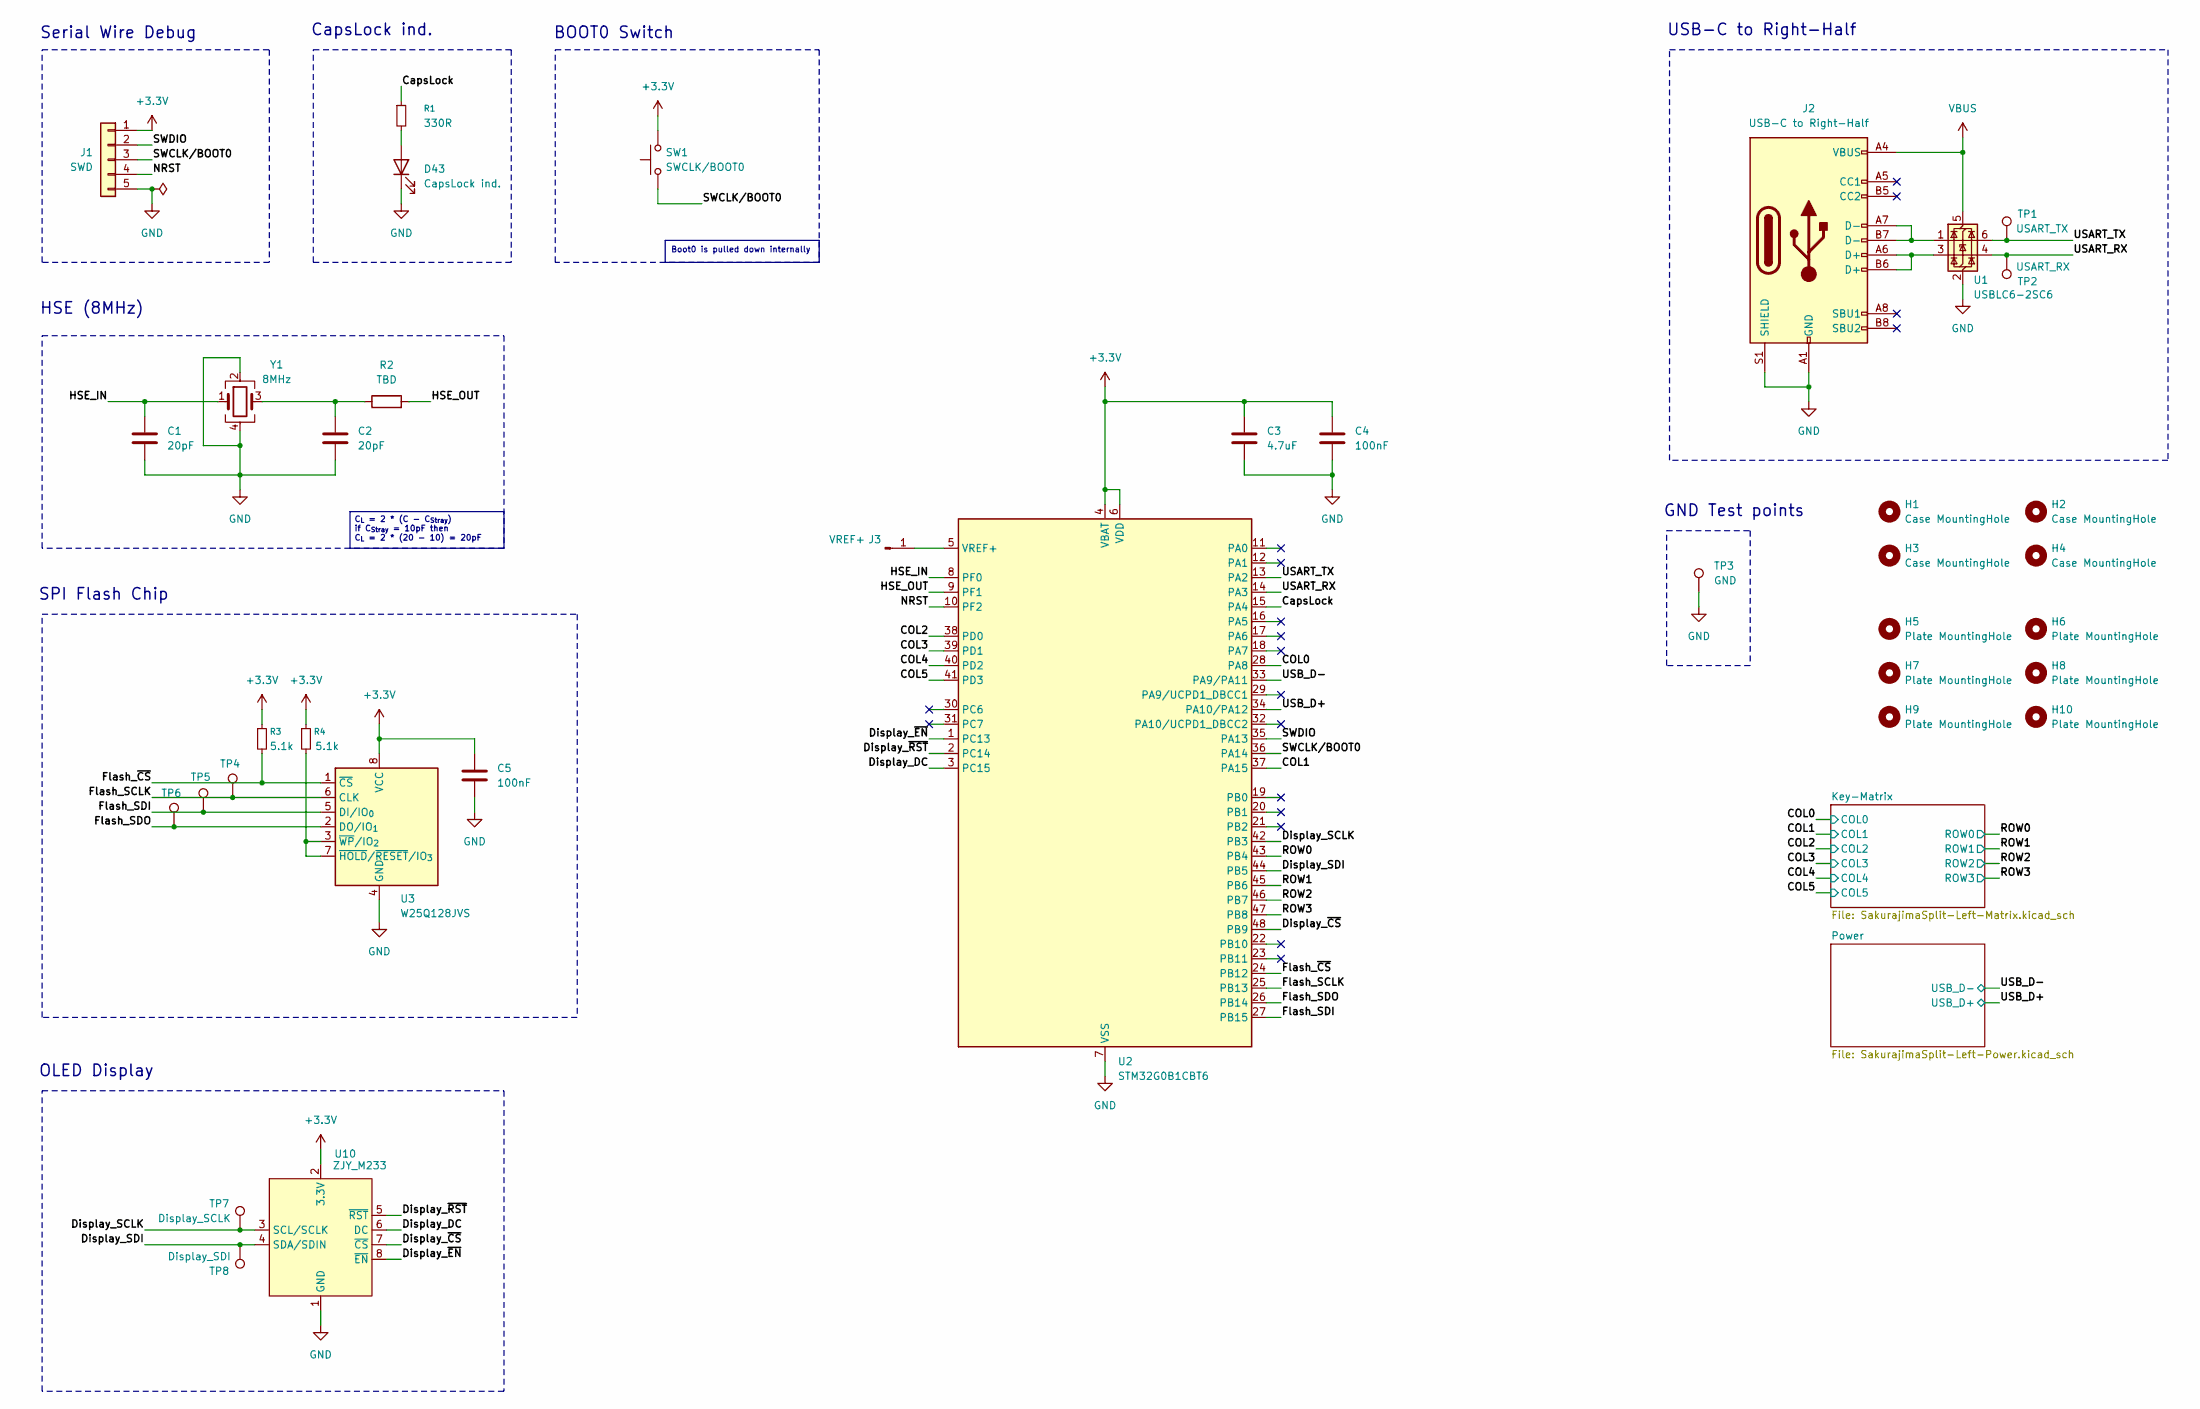
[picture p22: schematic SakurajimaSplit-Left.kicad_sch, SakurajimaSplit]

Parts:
C1, C2: 20pF; C_0402_1005Metric_Pad0.74x0.62mm_HandSolder; Manufacturer Part No. GRM1555C1H220JA01D
C3: 4.7uF; C_0805_2012Metric; Manufacturer Part No. GRM21BR61H475KE51L
C4, C5: 100nF; C_0603_1608Metric; Manufacturer Part No. GRM188R72A104KA35D
D43: CapsLock ind.; LED_0603_1608Metric; Manufacturer Part No. XL-1608UWC-04
H1, H2, H3, H4: Case MountingHole; MountingHole_3.2mm_M3_Pad_Via
H5, H6, H7, H8, H9, H10: Plate MountingHole; MountingHole_2.2mm_M2_Pad_Via
J1: SWD; PinHeader_1x05_P2.54mm_Horizontal
J2: USB-C to Right-Half; USB_C_Receptacle_G-Switch_GT-USB-7010ASV; Manufacturer Part No. GT-USB-7010ASV
J3: VREF+; SolderWirePad_1x01_SMD_1x2mm
R1: 330R; R_0603_1608Metric; Manufacturer Part No. SER0603F330R
R2: TBD; R_0603_1608Metric
R3, R4: 5.1k; R_0603_1608Metric; Manufacturer Part No. 0603WAF5101T5E
SW1: SWCLK/BOOT0; SW_Push_TS-1010B; Manufacturer Part No. TS-1010B-B-A
TP1: USART_TX; TestPoint_Pad_Circular_1.3mm
TP2: USART_RX; TestPoint_Pad_Circular_1.3mm
TP3: GND; TestPoint_Pad_Circular_1.3mm
TP4: Flash_SCLK; TestPoint_Pad_Circular_1.3mm
TP5: Flash_SDI; TestPoint_Pad_Circular_1.3mm
TP6: Flash_SDO; TestPoint_Pad_Circular_1.3mm
TP7: Display_SCLK; TestPoint_Pad_Circular_1.3mm
TP8: Display_SDI; TestPoint_Pad_Circular_1.3mm
U1: USBLC6-2SC6; SOT-23-6; Manufacturer Part No. USBLC6-4SC6
U2: STM32G0B1CBT6; LQFP-48_7x7mm_P0.5mm; Manufacturer Part No. STM32G0B1CBT6
U3: W25Q128JVS; SOIC-8_5.3x5.3mm_P1.27mm; Manufacturer Part No. W25Q128JVSIQ
U10: ZJY_M233; OLED_SSD1305
Y1: 8MHz; Crystal_SMD_3225-4Pin_3.2x2.5mm; Manufacturer Part No. X32258MSB4SI

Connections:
+3.3V: C3.1, C4.1, C5.1, J1.1, R3.1, R4.1, SW1.2, U2.4 (VBAT), U2.6 (VDD), U3.8 (VCC), U10.2 (3.3V); also elsewhere on the board
/Left-Half/COL0: U2.28 (PA8); also elsewhere on the board
/Left-Half/COL1: U2.37 (PA15); also elsewhere on the board
/Left-Half/COL2: U2.38 (PD0); also elsewhere on the board
/Left-Half/COL3: U2.39 (PD1); also elsewhere on the board
/Left-Half/COL4: U2.40 (PD2); also elsewhere on the board
/Left-Half/COL5: U2.41 (PD3); also elsewhere on the board
/Left-Half/CapsLock: R1.1, U2.15 (PA4)
/Left-Half/Display_DC: U2.3 (PC15), U10.6 (DC)
/Left-Half/Display_SCLK: TP7.1, U2.42 (PB3), U10.3 (SCL/SCLK)
/Left-Half/Display_SDI: TP8.1, U2.44 (PB5), U10.4 (SDA/SDIN)
/Left-Half/Display_~CS: U2.48 (PB9), U10.7 (~CS)
/Left-Half/Display_~EN: U2.1 (PC13), U10.8 (~EN)
/Left-Half/Display_~RST: U2.2 (PC14), U10.5 (~RST)
/Left-Half/Flash_SCLK: TP4.1, U2.25 (PB13), U3.6 (CLK)
/Left-Half/Flash_SDI: TP5.1, U2.27 (PB15), U3.5 (DI/IO_{0})
/Left-Half/Flash_SDO: TP6.1, U2.26 (PB14), U3.2 (DO/IO_{1})
/Left-Half/Flash_~CS: R3.2, U2.24 (PB12), U3.1 (~CS)
/Left-Half/HSE_IN: C1.1, U2.8 (PF0), Y1.1
/Left-Half/HSE_OUT: R2.2, U2.9 (PF1)
/Left-Half/NRST: J1.4, U2.10 (PF2)
/Left-Half/ROW0: U2.43 (PB4); also elsewhere on the board
/Left-Half/ROW1: U2.45 (PB6); also elsewhere on the board
/Left-Half/ROW2: U2.46 (PB7); also elsewhere on the board
/Left-Half/ROW3: U2.47 (PB8); also elsewhere on the board
/Left-Half/SWCLK/BOOT0: J1.3, SW1.1, U2.36 (PA14)
/Left-Half/SWDIO: J1.2, U2.35 (PA13)
/Left-Half/USART_RX: TP2.1, U1.4 (I/O2), U2.14 (PA3)
/Left-Half/USART_TX: TP1.1, U1.6 (I/O1), U2.13 (PA2)
/Left-Half/USB_D+: U2.34 (PA10/PA12); also elsewhere on the board
/Left-Half/USB_D-: U2.33 (PA9/PA11); also elsewhere on the board
GND: C1.2, C2.2, C3.2, C4.2, C5.2, D43.1 (K), J1.5, J2.A1 (GND), J2.A12 (GND), J2.B1 (GND), J2.B12 (GND), J2.S1 (SHIELD), TP3.1, U1.2 (GND), U2.7 (VSS), U3.4 (GND), U10.1 (GND), Y1.2, Y1.4; also elsewhere on the board
unnamed: C2.1, R2.1, Y1.3
unnamed: D43.2 (A), R1.2
unnamed: J2.A6 (D+), J2.B6 (D+), U1.3 (I/O2)
unnamed: J2.A7 (D-), J2.B7 (D-), U1.1 (I/O1)
unnamed: J3.1, U2.5 (VREF+)
unnamed: R4.2, U3.3 (~WP/IO_{2}), U3.7 (~HOLD/~RESET/IO_{3})
VBUS: J2.A4 (VBUS), J2.A9 (VBUS), J2.B4 (VBUS), J2.B9 (VBUS), U1.5 (VBUS); also elsewhere on the board

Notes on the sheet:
HSE (8MHz)
USB-C to Right-Half
SPI Flash Chip
GND Test points
Serial Wire Debug
CapsLock ind.
BOOT0 Switch
OLED Display
C_{L} = 2 * (C - C_{Stray}) if C_{Stray} = 10pF then C_{L} = 2 * (20 - 10) = 20pF
Boot0 is pulled down internally

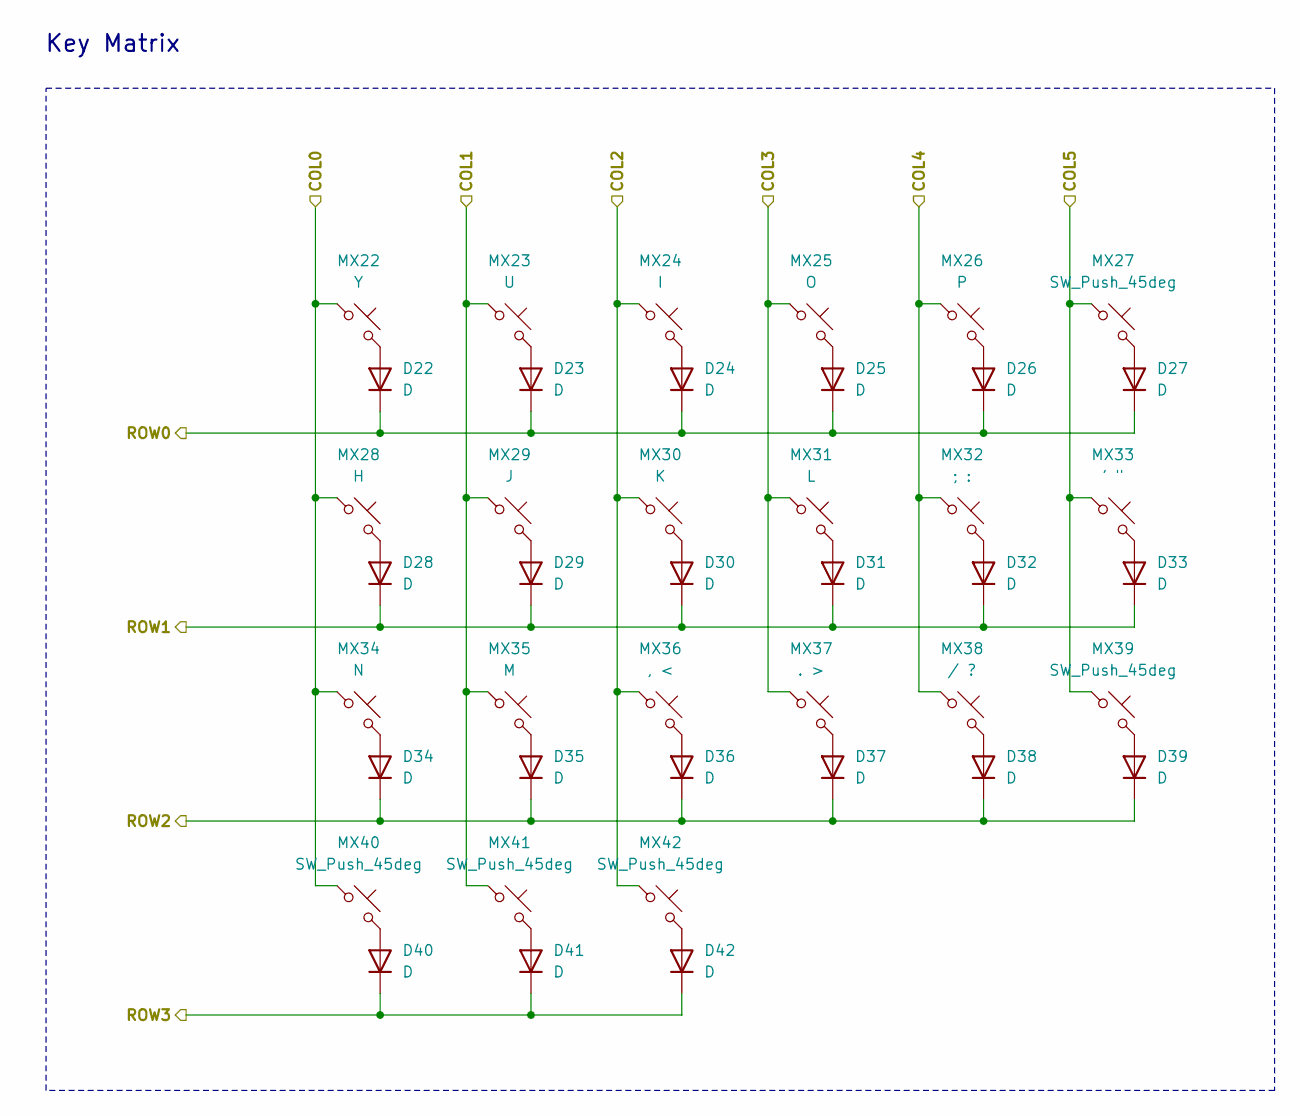
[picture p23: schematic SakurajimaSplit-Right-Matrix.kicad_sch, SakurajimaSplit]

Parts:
D22, D23, D24, D25, D26, D27, D28, D29, D30, D31, D32, D33, D34, D35, D36, D37, D38, D39, D40, D41, D42: D; D_SOD-123; Manufacturer Part No. 1N4148W
MX22: Y; SW_MX_1u
MX23: U; SW_MX_1u
MX24: I; SW_MX_1u
MX25: O; SW_MX_1u
MX26: P; SW_MX_1u
MX27, MX39, MX41, MX42: SW_Push_45deg; SW_MX_1u
MX28: H; SW_MX_1u
MX29: J; SW_MX_1u
MX30: K; SW_MX_1u
MX31: L; SW_MX_1u
MX32: ; :; SW_MX_1u
MX33: ' "; SW_MX_1u
MX34: N; SW_MX_1u
MX35: M; SW_MX_1u
MX36: , <; SW_MX_1u
MX37: . >; SW_MX_1u
MX38: / ?; SW_MX_1u
MX40: SW_Push_45deg; SW_MX_1.5u

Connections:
/Right-Half/COL0: MX22.1, MX28.1, MX34.1, MX40.1; also elsewhere on the board
/Right-Half/COL1: MX23.1, MX29.1, MX35.1, MX41.1; also elsewhere on the board
/Right-Half/COL2: MX24.1, MX30.1, MX36.1, MX42.1; also elsewhere on the board
/Right-Half/COL3: MX25.1, MX31.1, MX37.1; also elsewhere on the board
/Right-Half/COL4: MX26.1, MX32.1, MX38.1; also elsewhere on the board
/Right-Half/COL5: MX27.1, MX33.1, MX39.1; also elsewhere on the board
/Right-Half/ROW0: D22.1 (K), D23.1 (K), D24.1 (K), D25.1 (K), D26.1 (K), D27.1 (K); also elsewhere on the board
/Right-Half/ROW1: D28.1 (K), D29.1 (K), D30.1 (K), D31.1 (K), D32.1 (K), D33.1 (K); also elsewhere on the board
/Right-Half/ROW2: D34.1 (K), D35.1 (K), D36.1 (K), D37.1 (K), D38.1 (K), D39.1 (K); also elsewhere on the board
/Right-Half/ROW3: D40.1 (K), D41.1 (K), D42.1 (K); also elsewhere on the board
unnamed: D22.2 (A), MX22.2
unnamed: D23.2 (A), MX23.2
unnamed: D24.2 (A), MX24.2
unnamed: D25.2 (A), MX25.2
unnamed: D26.2 (A), MX26.2
unnamed: D27.2 (A), MX27.2
unnamed: D28.2 (A), MX28.2
unnamed: D29.2 (A), MX29.2
unnamed: D30.2 (A), MX30.2
unnamed: D31.2 (A), MX31.2
unnamed: D32.2 (A), MX32.2
unnamed: D33.2 (A), MX33.2
unnamed: D34.2 (A), MX34.2
unnamed: D35.2 (A), MX35.2
unnamed: D36.2 (A), MX36.2
unnamed: D37.2 (A), MX37.2
unnamed: D38.2 (A), MX38.2
unnamed: D39.2 (A), MX39.2
unnamed: D40.2 (A), MX40.2
unnamed: D41.2 (A), MX41.2
unnamed: D42.2 (A), MX42.2

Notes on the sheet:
Key Matrix

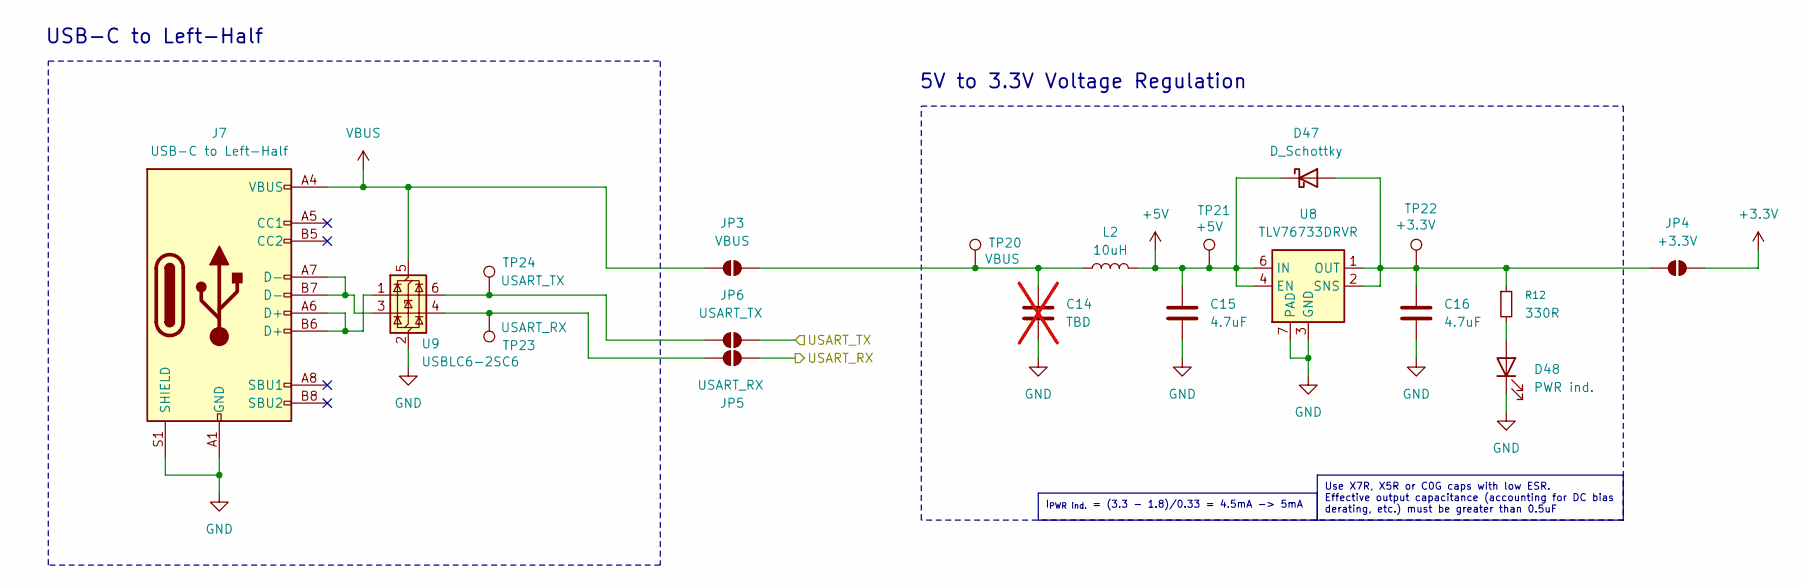
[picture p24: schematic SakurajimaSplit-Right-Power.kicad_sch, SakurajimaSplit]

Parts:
C14: TBD; C_0805_2012Metric; Manufacturer Part No. GRM21BR61H475KE51L; not fitted
C15, C16: 4.7uF; C_0805_2012Metric; Manufacturer Part No. GRM21BR61H475KE51L
D47: D_Schottky; D_SOD-123; Manufacturer Part No. B0530W-7-F
D48: PWR ind.; LED_0603_1608Metric; Manufacturer Part No. XL-1608UGC-04
J7: USB-C to Left-Half; USB_C_Receptacle_G-Switch_GT-USB-7010ASV; Manufacturer Part No. GT-USB-7010ASV
JP3: VBUS; SolderJumper-2_P1.3mm_Open_TrianglePad1.0x1.5mm
JP4: +3.3V; SolderJumper-2_P1.3mm_Open_TrianglePad1.0x1.5mm
JP5: USART_RX; SolderJumper-2_P1.3mm_Open_TrianglePad1.0x1.5mm
JP6: USART_TX; SolderJumper-2_P1.3mm_Open_TrianglePad1.0x1.5mm
L2: 10uH; L_1210_3225Metric; Manufacturer Part No. DFE322512F-100M
R12: 330R; R_0603_1608Metric; Manufacturer Part No. SER0603F330R
TP20: VBUS; TestPoint_Pad_Circular_1.3mm
TP21: +5V; TestPoint_Pad_Circular_1.3mm
TP22: +3.3V; TestPoint_Pad_Circular_1.3mm
TP23: USART_RX; TestPoint_Pad_Circular_1.3mm
TP24: USART_TX; TestPoint_Pad_Circular_1.3mm
U8: TLV76733DRVR; WSON-6-1EP_2x2mm_P0.65mm_EP1x1.6mm_ThermalVias; Manufacturer Part No. TLV76733DRVR
U9: USBLC6-2SC6; SOT-23-6; Manufacturer Part No. USBLC6-4SC6

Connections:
+3.3V: JP4.2 (B); also elsewhere on the board
+5V: C15.1, D47.1 (K), L2.2, TP21.1, U8.4 (EN), U8.6 (IN); also elsewhere on the board
/Right-Half/USART_RX: JP5.2 (B); also elsewhere on the board
/Right-Half/USART_TX: JP6.2 (B); also elsewhere on the board
GND: C14.2, C15.2, C16.2, D48.1 (K), J7.A1 (GND), J7.A12 (GND), J7.B1 (GND), J7.B12 (GND), J7.S1 (SHIELD), U8.3 (GND), U8.5 (GND), U8.7 (PAD), U9.2 (GND); also elsewhere on the board
unnamed: C16.1, D47.2 (A), JP4.1 (A), R12.1, TP22.1, U8.1 (OUT), U8.2 (SNS)
unnamed: D48.2 (A), R12.2
unnamed: J7.A6 (D+), J7.B6 (D+), U9.1 (I/O1)
unnamed: J7.A7 (D-), J7.B7 (D-), U9.3 (I/O2)
unnamed: C14.1, JP3.2 (B), L2.1, TP20.1
unnamed: JP5.1 (A), TP23.1, U9.4 (I/O2)
unnamed: JP6.1 (A), TP24.1, U9.6 (I/O1)
VBUS: J7.A4 (VBUS), J7.A9 (VBUS), J7.B4 (VBUS), J7.B9 (VBUS), JP3.1 (A), U9.5 (VBUS); also elsewhere on the board

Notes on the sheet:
USB-C to Left-Half
5V to 3.3V Voltage Regulation
Use X7R, X5R or C0G caps with low ESR. Effective output capacitance (accounting for DC bias derating, etc.) must be greater than 0.5uF
I_{PWR ind.} = (3.3 - 1.8)/0.33 = 4.5mA -> 5mA

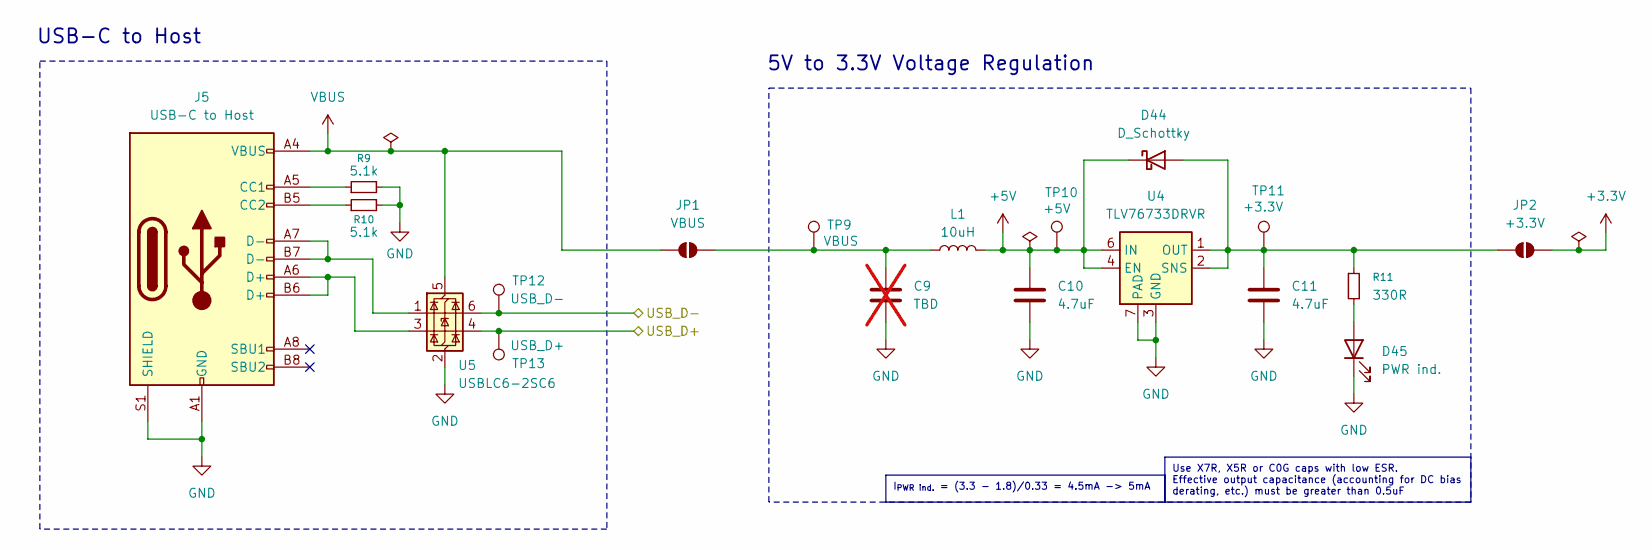
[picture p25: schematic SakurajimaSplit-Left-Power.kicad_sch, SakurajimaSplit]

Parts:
C9: TBD; C_0805_2012Metric; Manufacturer Part No. GRM21BR61H475KE51L; not fitted
C10, C11: 4.7uF; C_0805_2012Metric; Manufacturer Part No. GRM21BR61H475KE51L
D44: D_Schottky; D_SOD-123; Manufacturer Part No. B0530W-7-F
D45: PWR ind.; LED_0603_1608Metric; Manufacturer Part No. XL-1608UGC-04
J5: USB-C to Host; USB_C_Receptacle_G-Switch_GT-USB-7010ASV; Manufacturer Part No. GT-USB-7010ASV
JP1: VBUS; SolderJumper-2_P1.3mm_Open_TrianglePad1.0x1.5mm
JP2: +3.3V; SolderJumper-2_P1.3mm_Open_TrianglePad1.0x1.5mm
L1: 10uH; L_1210_3225Metric; Manufacturer Part No. DFE322512F-100M
R9, R10: 5.1k; R_0603_1608Metric; Manufacturer Part No. 0603WAF5101T5E
R11: 330R; R_0603_1608Metric; Manufacturer Part No. SER0603F330R
TP9: VBUS; TestPoint_Pad_Circular_1.3mm
TP10: +5V; TestPoint_Pad_Circular_1.3mm
TP11: +3.3V; TestPoint_Pad_Circular_1.3mm
TP12: USB_D-; TestPoint_Pad_Circular_1.3mm
TP13: USB_D+; TestPoint_Pad_Circular_1.3mm
U4: TLV76733DRVR; WSON-6-1EP_2x2mm_P0.65mm_EP1x1.6mm_ThermalVias; Manufacturer Part No. TLV76733DRVR
U5: USBLC6-2SC6; SOT-23-6; Manufacturer Part No. USBLC6-4SC6

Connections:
+3.3V: JP2.2 (B); also elsewhere on the board
+5V: C10.1, D44.1 (K), L1.2, TP10.1, U4.4 (EN), U4.6 (IN); also elsewhere on the board
/Left-Half/USB_D+: TP13.1, U5.4 (I/O2); also elsewhere on the board
/Left-Half/USB_D-: TP12.1, U5.6 (I/O1); also elsewhere on the board
GND: C9.2, C10.2, C11.2, D45.1 (K), J5.A1 (GND), J5.A12 (GND), J5.B1 (GND), J5.B12 (GND), J5.S1 (SHIELD), R9.2, R10.2, U4.3 (GND), U4.5 (GND), U4.7 (PAD), U5.2 (GND); also elsewhere on the board
unnamed: C11.1, D44.2 (A), JP2.1 (A), R11.1, TP11.1, U4.1 (OUT), U4.2 (SNS)
unnamed: D45.2 (A), R11.2
unnamed: J5.A5 (CC1), R9.1
unnamed: J5.B5 (CC2), R10.1
unnamed: J5.A6 (D+), J5.B6 (D+), U5.3 (I/O2)
unnamed: J5.A7 (D-), J5.B7 (D-), U5.1 (I/O1)
unnamed: C9.1, JP1.2 (B), L1.1, TP9.1
VBUS: J5.A4 (VBUS), J5.A9 (VBUS), J5.B4 (VBUS), J5.B9 (VBUS), JP1.1 (A), U5.5 (VBUS); also elsewhere on the board

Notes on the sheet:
5V to 3.3V Voltage Regulation
USB-C to Host
I_{PWR ind.} = (3.3 - 1.8)/0.33 = 4.5mA -> 5mA
Use X7R, X5R or C0G caps with low ESR. Effective output capacitance (accounting for DC bias derating, etc.) must be greater than 0.5uF

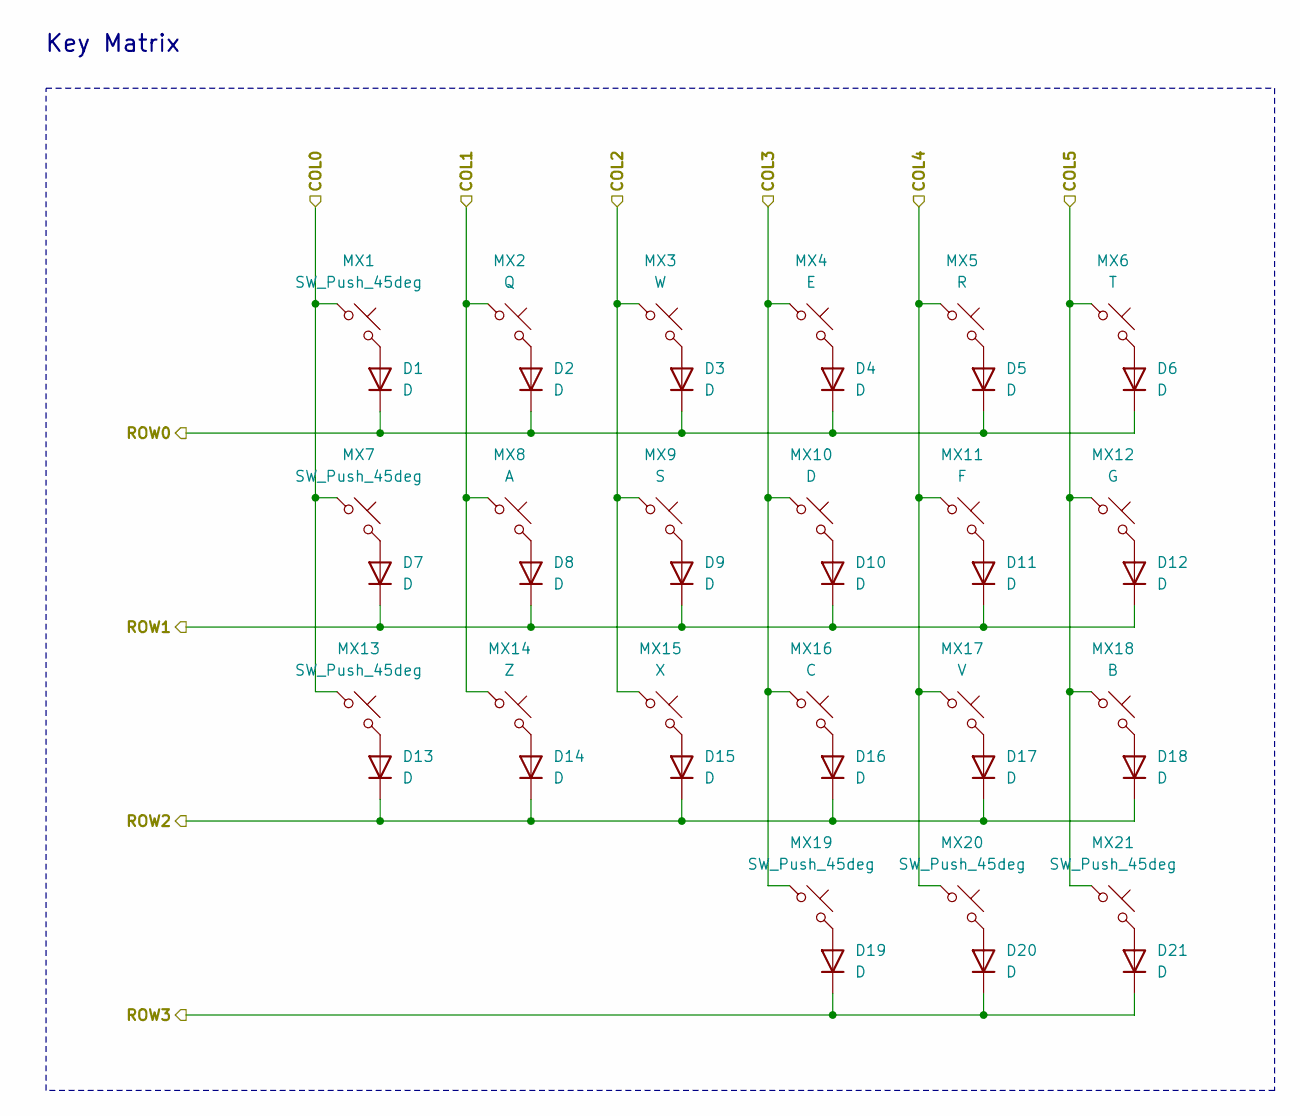
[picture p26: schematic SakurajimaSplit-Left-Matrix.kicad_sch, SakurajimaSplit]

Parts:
D1, D2, D3, D4, D5, D6, D7, D8, D9, D10, D11, D12, D13, D14, D15, D16, D17, D18, D19, D20, D21: D; D_SOD-123; Manufacturer Part No. 1N4148W
MX1, MX7, MX13, MX19, MX20: SW_Push_45deg; SW_MX_1u
MX2: Q; SW_MX_1u
MX3: W; SW_MX_1u
MX4: E; SW_MX_1u
MX5: R; SW_MX_1u
MX6: T; SW_MX_1u
MX8: A; SW_MX_1u
MX9: S; SW_MX_1u
MX10: D; SW_MX_1u
MX11: F; SW_MX_1u
MX12: G; SW_MX_1u
MX14: Z; SW_MX_1u
MX15: X; SW_MX_1u
MX16: C; SW_MX_1u
MX17: V; SW_MX_1u
MX18: B; SW_MX_1u
MX21: SW_Push_45deg; SW_MX_1.5u

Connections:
/Left-Half/COL0: MX1.1, MX7.1, MX13.1; also elsewhere on the board
/Left-Half/COL1: MX2.1, MX8.1, MX14.1; also elsewhere on the board
/Left-Half/COL2: MX3.1, MX9.1, MX15.1; also elsewhere on the board
/Left-Half/COL3: MX4.1, MX10.1, MX16.1, MX19.1; also elsewhere on the board
/Left-Half/COL4: MX5.1, MX11.1, MX17.1, MX20.1; also elsewhere on the board
/Left-Half/COL5: MX6.1, MX12.1, MX18.1, MX21.1; also elsewhere on the board
/Left-Half/ROW0: D1.1 (K), D2.1 (K), D3.1 (K), D4.1 (K), D5.1 (K), D6.1 (K); also elsewhere on the board
/Left-Half/ROW1: D7.1 (K), D8.1 (K), D9.1 (K), D10.1 (K), D11.1 (K), D12.1 (K); also elsewhere on the board
/Left-Half/ROW2: D13.1 (K), D14.1 (K), D15.1 (K), D16.1 (K), D17.1 (K), D18.1 (K); also elsewhere on the board
/Left-Half/ROW3: D19.1 (K), D20.1 (K), D21.1 (K); also elsewhere on the board
unnamed: D1.2 (A), MX1.2
unnamed: D2.2 (A), MX2.2
unnamed: D3.2 (A), MX3.2
unnamed: D4.2 (A), MX4.2
unnamed: D5.2 (A), MX5.2
unnamed: D6.2 (A), MX6.2
unnamed: D7.2 (A), MX7.2
unnamed: D8.2 (A), MX8.2
unnamed: D9.2 (A), MX9.2
unnamed: D10.2 (A), MX10.2
unnamed: D11.2 (A), MX11.2
unnamed: D12.2 (A), MX12.2
unnamed: D13.2 (A), MX13.2
unnamed: D14.2 (A), MX14.2
unnamed: D15.2 (A), MX15.2
unnamed: D16.2 (A), MX16.2
unnamed: D17.2 (A), MX17.2
unnamed: D18.2 (A), MX18.2
unnamed: D19.2 (A), MX19.2
unnamed: D20.2 (A), MX20.2
unnamed: D21.2 (A), MX21.2

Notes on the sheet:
Key Matrix

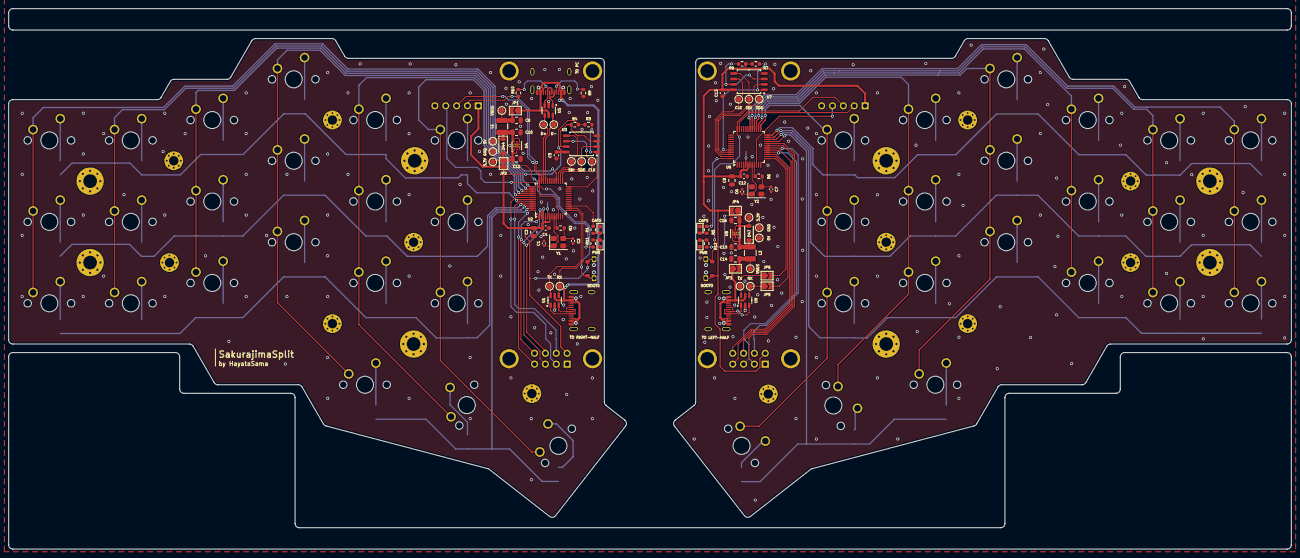
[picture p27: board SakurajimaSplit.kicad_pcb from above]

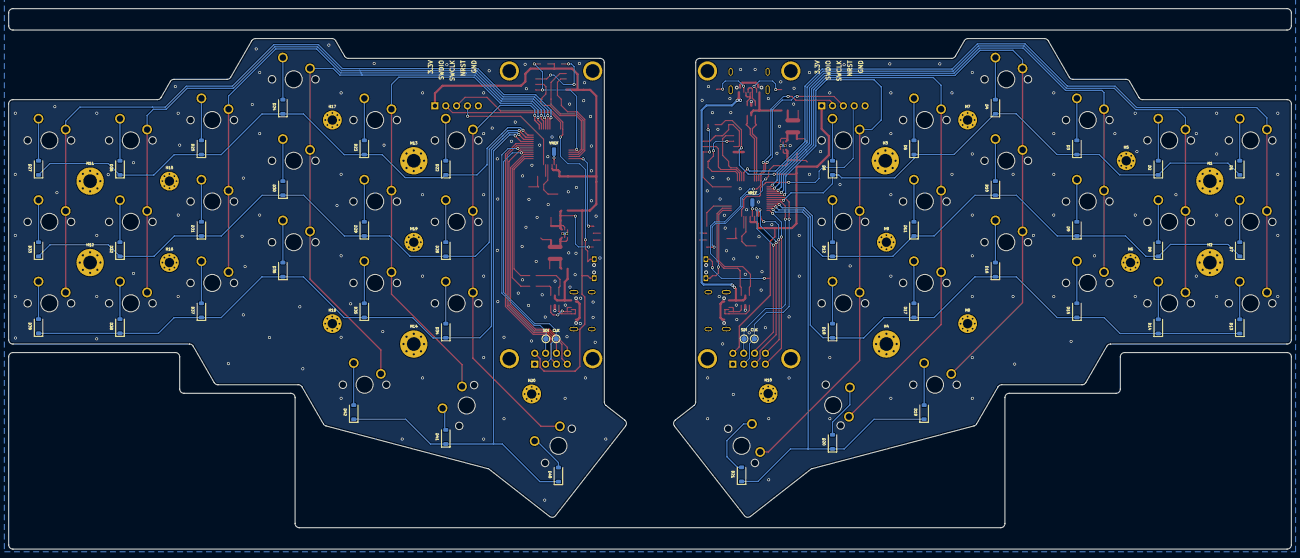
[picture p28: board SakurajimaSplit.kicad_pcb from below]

Board: 2 copper layers, 300.0 x 126.4 mm, 192 parts (70 on the bottom side), 128 nets.

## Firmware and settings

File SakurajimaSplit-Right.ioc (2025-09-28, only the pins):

Mcu.UserName=STM32G0B1CBTx
PA13.GPIO_Label=SWDIO
PA13.Signal=SYS_SWDIO
PA14-BOOT0.GPIO_Label=SWCLK/BOOT0
PA14-BOOT0.Signal=SYS_SWCLK
PA2.GPIO_Label=USART_TX
PA2.Signal=USART2_TX
PA3.GPIO_Label=USART_RX
PA3.Signal=USART2_RX
PA4.GPIO_Label=Display_EN
PA4.Signal=GPIO_Output
PA5.GPIO_Label=Display_SCLK
PA5.Signal=SPI1_SCK
PA6.GPIO_Label=Display_CS
PA6.Signal=GPIO_Output
PA7.GPIO_Label=Display_SDI
PA7.Signal=SPI1_MOSI
PA8.GPIO_Label=COL3
PA8.Signal=GPIO_Output
PA9.GPIO_Label=COL4
PA9.Signal=GPIO_Output
PB0.GPIO_Label=Display_DC
PB0.Signal=GPIO_Output
PB1.GPIO_Label=Display_RST
PB1.Signal=GPIO_Output
PB10.GPIO_Label=ROW2
PB10.Signal=GPIO_Input
PB11.GPIO_Label=ROW1
PB11.Signal=GPIO_Input
PB12.GPIO_Label=ROW0
PB12.Signal=GPIO_Input
PB13.GPIO_Label=COL0
PB13.Signal=GPIO_Output
PB14.GPIO_Label=COL1
PB14.Signal=GPIO_Output
PB15.GPIO_Label=COL2
PB15.Signal=GPIO_Output
PB2.GPIO_Label=ROW3
PB2.Signal=GPIO_Input
PB5.GPIO_Label=Flash_CS
PB5.Signal=GPIO_Output
PB6.GPIO_Label=Flash_SDO
PB6.Signal=SPI2_MISO
PB7.GPIO_Label=Flash_SDI
PB7.Signal=SPI2_MOSI
PB8.GPIO_Label=Flash_SCLK
PB8.Signal=SPI2_SCK
PB9.GPIO_Label=CapsLock
PB9.Signal=GPIO_Output
PC6.GPIO_Label=COL5
PC6.Signal=GPIO_Output
PF2-NRST.GPIO_Label=NRST
PF2-NRST.Signal=GPIO_Input

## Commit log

2025-05-22 chore: setup project structure
    update .gitignore to exclude kicad related temp files
    add project license
2025-05-22 feat(schematic): basic circuitry for the mcu
    [SakurajimaSplit-Left.kicad_sch, SakurajimaSplit-Right.kicad_sch, SakurajimaSplit.kicad_pcb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]
2025-05-22 feat(schematic): add key matrix
    [SakurajimaSplit-Left-Matrix.kicad_sch, SakurajimaSplit-Left.kicad_sch]
2025-06-27 feat(sch): add host USB connection and power circuit
    [SakurajimaSplit-Left-Matrix.kicad_sch, SakurajimaSplit-Left-Power.kicad_sch, SakurajimaSplit-Left.kicad_sch]
2025-06-28 feat(sch): add USB to right-half circuit
    [SakurajimaSplit-Left-Matrix.kicad_sch, SakurajimaSplit-Left-Power.kicad_sch, SakurajimaSplit-Left.kicad_sch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]
2025-06-28 feat(sch): add rotary encoder
    [SakurajimaSplit-Left.kicad_sch]
2025-06-29 feat(sch): add symbol and footprint for ssd1305 oled display module
2025-06-29 feat(sch): add OLED display
    [SakurajimaSplit-Left.kicad_sch]
2025-07-01 feat(sch): mcu connections, test points and schematic cleanup
    [SakurajimaSplit-Left-Power.kicad_sch, SakurajimaSplit-Left.kicad_sch, SakurajimaSplit.kicad_sch]
2025-08-10 feat(sch): cleanup and anotate schematic, choose components
    - Fixed mistakes in schematic
    - Anotated the schematic
    - Found and chose components
    - Added GND test points
    - Ran ERC and fixed all errors and warnings
    [SakurajimaSplit-Left-Matrix.kicad_sch, SakurajimaSplit-Left-Power.kicad_sch, SakurajimaSplit-Left.kicad_sch]
2025-08-10 feat(sch): design right half of the keyboard
    [SakurajimaSplit-Left-Power.kicad_sch, SakurajimaSplit-Right-Matrix.kicad_sch, SakurajimaSplit-Right-Power.kicad_sch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]
2025-08-10 fix(sch): fix ERC errors regarding power flags
    [SakurajimaSplit-Right-Power.kicad_sch, SakurajimaSplit-Right.kicad_sch]
2025-08-10 feat(pcb): assign all footprints
    [SakurajimaSplit-Left-Matrix.kicad_sch, SakurajimaSplit-Left-Power.kicad_sch, SakurajimaSplit-Left.kicad_sch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]
2025-08-10 fix(sch): fix matrix diode designators not starting from 1
    [SakurajimaSplit-Left-Matrix.kicad_sch, SakurajimaSplit-Left-Power.kicad_sch, SakurajimaSplit-Left.kicad_sch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]
2025-08-11 feat(pcb): setup board and define manufacturing constraints
    [SakurajimaSplit.kicad_pcb]
2025-08-11 feat(pcb): add missing 3d models
    [SakurajimaSplit.kicad_pcb]
2025-08-11 feat(pcb): add temporary OLED module 3d model
    [SakurajimaSplit.kicad_pcb]
2025-09-16 feat(sch): add spi flash, remove rotary encoder, fix footprints
    [SakurajimaSplit-Left-Power.kicad_sch, SakurajimaSplit-Left.kicad_sch, SakurajimaSplit-Right-Power.kicad_sch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]
2025-09-16 fix(sch): remove encoder net labels, update mountinghole footprints
    [SakurajimaSplit-Left.kicad_sch, SakurajimaSplit-Right.kicad_sch]
2025-09-16 fix(sch): swap LEDs with their series resistors
    [SakurajimaSplit-Left-Power.kicad_sch, SakurajimaSplit-Left.kicad_sch, SakurajimaSplit-Right-Power.kicad_sch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]
2025-09-16 fix(sch): fix wrong footprint for MX21 & MX40
    [SakurajimaSplit-Left-Matrix.kicad_sch, SakurajimaSplit-Right-Matrix.kicad_sch]
2025-09-16 feat(pcb): new kle layout
2025-09-18 feat(pcb): design rough layout and update schematic accordingly
    [SakurajimaSplit-Left.kicad_sch, SakurajimaSplit.kicad_pcb]
2025-09-25 feat(pcb): finish designing rough layout and update schematic
    - Removed unused MCU pads
    - Removed some GND testpoints
    - Updated MCU connections based on PCB layout and MCU orientation
    - Updated key matrix layout for a less aggressive one which feels more
    comfortable and more visually pleasing
    - Re-annotated schematic
    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
    [SakurajimaSplit-Left-Power.kicad_sch, SakurajimaSplit-Left.kicad_sch, SakurajimaSplit-Right-Power.kicad_sch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]
2025-09-25 feat(pcb): fine tune pcb layout
    - fine tuned pcb layout
    - swaped TX and RX pins of right half for better routing
    [SakurajimaSplit-Right-Power.kicad_sch, SakurajimaSplit.kicad_pcb]
2025-09-26 feat(pcb): route left half
    [SakurajimaSplit-Left.kicad_sch, SakurajimaSplit.kicad_pcb]
2025-09-27 feat(pcb): route right half
    [SakurajimaSplit-Right.kicad_sch, SakurajimaSplit.kicad_pcb]
2025-09-28 fix(pcb): fix DRC errors, fix silkscreen, fix some routing
    [SakurajimaSplit-Right.kicad_sch, SakurajimaSplit.kicad_pcb]
2025-09-29 feat(pcb): add mounting holes, fix some bugs
    [SakurajimaSplit-Left.kicad_sch, SakurajimaSplit-Right-Power.kicad_sch, SakurajimaSplit-Right.kicad_sch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]
2025-09-30 feat(pcb): add stitching vias
    [SakurajimaSplit.kicad_pcb]
2025-09-30 feat(pcb): add teardrops
2025-10-01 fix(pcb): fix teardrops, routing, silkscreen
2025-10-01 feat(pcb): add mousebites and finish pcb panel
2025-10-02 fix(pcb): fix a mousebite, fix fab layer
2025-10-02 fix(pcb): fix swd header placement, fix revision silkscreen
2025-10-03 feat(pcb): add Mai and Sakuta silkscreen
2025-10-04 fix(pcb): fix some inconsistencies before manufacturing
2026-05-11 feat(mech): add final CAD model of the case
    [MX.STEP]
2026-05-11 feat: add manufacturing files
    [SakurajimaSplit-BOM.xlsx, SakurajimaSplit-Left Case.step, SakurajimaSplit-Left Case.stl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]
